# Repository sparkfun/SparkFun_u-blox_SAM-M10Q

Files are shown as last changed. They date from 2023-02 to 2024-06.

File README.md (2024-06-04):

SparkFun GPS Breakout, Chip Antenna - SAM-M10Q (Qwiic)
========================================

SparkFun GPS Breakout, Chip Antenna - SAM-M10Q (Qwiic) (https://www.sparkfun.com/products/21834)

[*SparkFun GPS Breakout, Chip Antenna - SAM-M10Q (Qwiic) (GPS-21834)*](https://www.sparkfun.com/products/21834)

The SparkFun SAM-M10Q GPS Breakout features the the SAM-M10Q chip-antenna module from u-blox<sup>&copy;</sup>. The SAM-M10Q can receive up to four GNSS constellations at once which improves time-to-fix and positional accuracy even in areas with limited view of the sky. The module includes a built-in chip antenna and is compatible with the L1 band on all five GNSS constellations (GPS L1 C/A, QZSS L1 C/A L1S, GLONASS L1OF, BeiDou B1C, and Galileo E1B/C). It has a horizontal position accuracy of 1.5 m, max update rate of 18 Hz when transmitting with just one GNSS constellation (max of 5Hz with 4 GNSS) and a cold start time to fix of 23 seconds. The board includes a rechargeable 3V/1mAh battery to provide backup power for up to four hours to maintain a hot start of just 1 second.

Repository Contents
-------------------

* **/Documentation** - Data sheets, additional product information
* **/Hardware** - Eagle design files (.brd, .sch)
* **/docs** - Hookup Guide files for the GPS Breakout, Chip Antenna - SAM-M10Q (Qwiic)
* **/Production** - Production panel files (.brd)

Documentation
--------------
* **[Library](https://github.com/sparkfun/SparkFun_u-blox_GNSS_v3)** - Arduino library for the SparkFun u-blox boards v3.
* **[Hookup Guide](https://docs.sparkfun.com/SparkFun_u-blox_SAM-M10Q)** - Basic hookup guide for the GPS Breakout, Chip Antenna - SAM-M10Q (Qwiic).

Product Versions
----------------

* [GPS-21834](https://www.sparkfun.com/products/21834) - Initial release of GPS Breakout, Chip Antenna - SAM-M10Q (Qwiic)

License Information
-------------------

This product is _**open source**_! 

Please review the LICENSE.md file for license information. 

If you have any questions or concerns on licensing, please contact technical support on our [SparkFun forums](https://forum.sparkfun.com/viewforum.php?f=152).

Distributed as-is; no warranty is given.

- Your friends at SparkFun.

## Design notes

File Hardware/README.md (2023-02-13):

SparkFun <PRODUCT NAME> Design Files
=====================================

The .sch and .brd files hare are Eagle CAD schematic and PCB design files from SparkFun Electronics.
A freeware version of Autodesk Eagle can be found [here](https://www.autodesk.com/products/eagle/free-download).

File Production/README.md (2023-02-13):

SparkFun <PRODUCT NAME> Production Files
=========================================

These are the production files SparkFun uses for printing PCBs.

License Information
-------------------
This product is open source! 

The hardware is released under [Creative Commons ShareAlike 4.0 International](https://creativecommons.org/licenses/by-sa/4.0/).

Please use, reuse, and modify these files as you see fit. Please maintain attribution to SparkFun Electronics and release anything derivative under the same license.

Distributed as-is; no warranty is given.

- Your friends at SparkFun.

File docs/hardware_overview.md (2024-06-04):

Let&apos;s take a closer look at the SAM-M10Q and other hardware on this GPS breakout.

## SAM-M10Q

The SAM-M10Q GNSS module from u-blox is from the M10 series of modules and features a chip antenna. The chip antenna removes the need for an external antenna and we designed this board to mount the module on a large ground plane to help maximize the reception quality. 

<center>
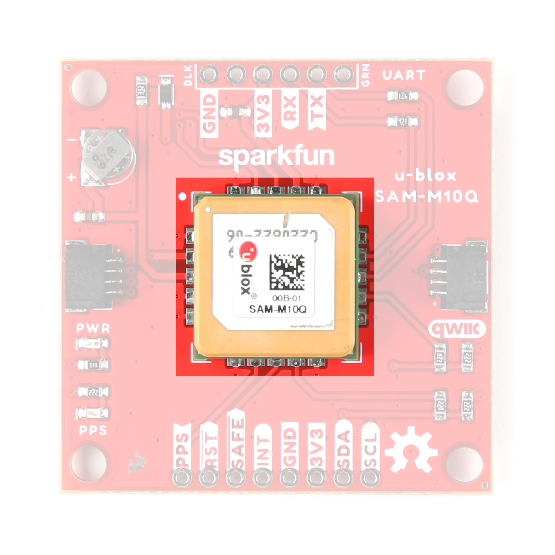
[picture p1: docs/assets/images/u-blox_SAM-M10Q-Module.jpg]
SAM-M10Q Module

</center>

The module can receive up to four GNSS constellations at a time allowing for excellent signal quality and reliability even in areas with limited view of the sky. More GNSS locks reduce the update rate of the SAM-M10Q so users should take into consideration which is more important for their application. The SAM-M10Q has a max altitude of 80,000m and max velocity of 500m/s with an acceleration limit of &le; 4g. The module also has a time pulse signal with a RMS accuracy of 30ns. This signal defaults to 1 pulse per second but is configurable between 0.25Hz to 10MHz. For a complete overview of the SAM-M10Q refer to the [datasheet](./assets/component_documentation/SAM-M10Q_DataSheet_UBX-22013293.pdf) and [integration manual](./assets/component_documentation/SAM-M10Q_IntegrationManual_UBX-22020019.pdf). The tables below outline some of the SAM-M10Q&apos;s capabilities in single-GNSS and multi-GNSS modes:

<table>
    <th colspan="7"><b>Single GNSS Constellation Mode</b></th>
    <tr align="center">
        <td align="left">Parameter</td>
        <td>Condition</td>
        <td>Units</td>    
        <td>GPS</td>    
        <td>GLONASS</td>        
        <td>Galileo</td> 
        <td>BeiDou</td>
    </tr>   
    <tr align="center">
        <td align="left">Horizontal Position Accuracy</td>
        <td>-</td>
        <td>m</td>
        <td>1.5</td>
        <td>4</td>
        <td>3</td>
        <td>2</td>
    </tr>
    <tr align="center">
        <td align="left">Max Navigation Update Rate</td>
        <td>-</td>
        <td>Hz</td> 
        <td>18</td>
        <td>18</td>
        <td>18</td>
        <td>18</td>       
    </tr> 
    <tr align="center">
        <td rowspan="2" align="left">Time-To-First-Fix</td>
        <td>Cold Start</td>
        <td rowspan="2">s</td>
        <td>29</td>
        <td>27</td>
        <td>41</td>
        <td>56</td>
    </tr>
    <tr align="center"> 
        <td>Hot Start</td>
        <td>1</td> 
       	<td>1</td>
        <td>1</td> 
        <td>1</td>
    </tr>
    <tr align="center">
        <td align="left" rowspan="4">Sensitivity</td>
        <td>Cold Start</td>
        <td rowspan="4">dBm</td>
        <td>-146</td>
        <td>-145</td> 
        <td>-139</td> 
        <td>-134</td>
    </tr>
    <tr align="center"> 
        <td>Hot Start</td> 
        <td>-157</td> 
        <td>-157</td>
        <td>-153</td> 
        <td>-155</td>
    </tr>   
    <tr align="center">
        <td>Tracking and Navigation</td>
        <td>-165</td>
        <td>-164</td>
        <td>-159</td> 
        <td>-161</td> 
    </tr>
    <tr align="center">
        <td>Reacquisition</td> 
        <td>-158</td> 
        <td>-156</td> 
        <td>-152</td> 
        <td>-154</td> 
    </tr>
</table>
<table>
    <th colspan="7">Multi-GNSS Constellation Modes</th>
    <tr align="center">
        <td align="left">Parameter</td>
        <td>Condition</td>
        <td>Units</td>
        <td>GPS+GAL+BDS+GLO</td>
        <td>GPS+GAL+GLO</td>
        <td>GPS+GAL+BDS</td>
        <td>GPS+GAL</td>
    </tr>
    <tr align="center">
        <td align="left">Max Navigation Update Rate</td>
        <td>-</td>
        <td>Hz</td>
        <td>5</td>
        <td>7</td>
        <td>8</td>
        <td>10</td>
    </tr>
    <tr align="center">
        <td align="left">Horizontal Position Accuracy</td>
        <td>-</td>
        <td>m</td>
        <td>1.5</td>
        <td>1.5</td>
        <td>1.5</td>
        <td>1.5</td>
    </tr>
    <tr align="center">
        <td align="left" rowspan="2">Time-To-First-Fix</td>
        <td>Cold Start</td>
        <td rowspan="2">s</td>
        <td>23</td>
        <td>23</td>
        <td>28</td>
        <td>28</td>
    </tr>
    <tr align="center">
        <td>Hot Start</td>
        <td>1</td>
        <td>1</td>
        <td>1</td>
        <td>1</td>
    </tr>
    <tr align="center">
        <td align="left" rowspan="4">Sensitivity</td>
        <td>Tracking and Navigation</td>
        <td rowspan="4">dBm</td>
        <td>-165</td>
        <td>-165</td>
        <td>-165</td>
        <td>-165</td>
    </tr>
    <tr align="center">
        <td>Reacquisition</td>
        <td>-158</td>
        <td>-158</td>
        <td>-158</td>
        <td>-158</td>
    </tr>
    <tr align="center">
        <td>Cold Start</td>
        <td>-146</td>
        <td>-146</td>
        <td>-146</td>
        <td>-146</td>
    </tr>
    <tr align="center">
        <td>Hot Start</td>
        <td>-157</td>
        <td>-157</td>
        <td>-157</td>
        <td>-157</td>
    </tr>
</table>

## Backup Battery

This breakout includes a small 3V/1mAh lithium battery to power relevant systems inside the SAM-M10Q that allow for a quick acquisition of satellites. On first start up, time to first fix is about ~23 seconds, but after it has a lock the battery allows for a hot start and can drop the time to fix down to one second. A hot start and lasts for four hours after the board is powered down and the board charges it slowly when powered.

<center>
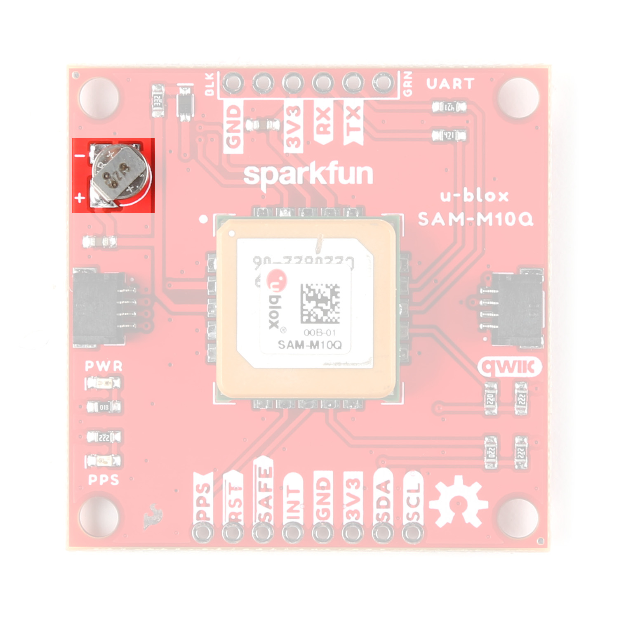
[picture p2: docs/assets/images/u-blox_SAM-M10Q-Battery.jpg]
Backup Battery

</center>

## Qwiic & Through Hole Connections

As the name suggests, this breakout includes a pair of Qwiic connectors to integrate the SAM-M10Q into an existing Qwiic system. The board also includes a pair of 0.1"-spaced plated through hole (PTH) headers for the SAM-M10Q's UART interface as well as several other function pins.

<center>
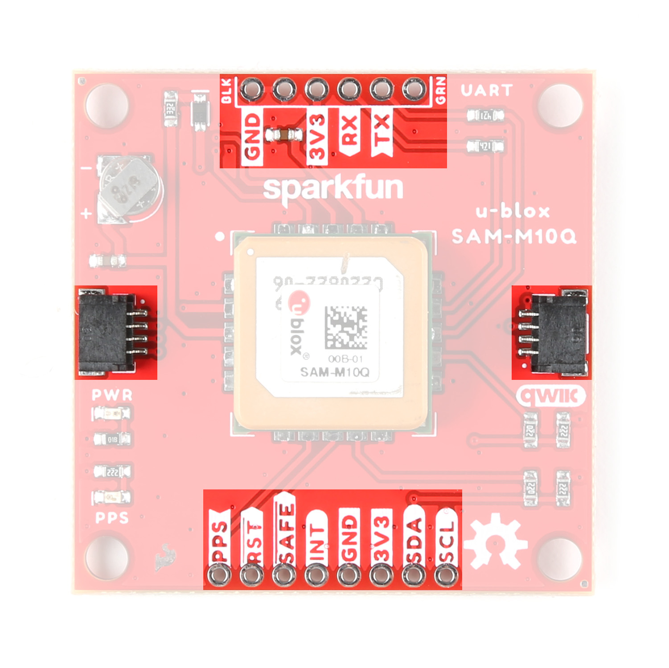
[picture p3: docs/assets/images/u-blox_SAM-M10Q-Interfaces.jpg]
Communication Interfaces

</center>

### Qwiic Connectors

The two Qwiic connectors route the I<sup>2</sup>C lines (SDA/SCL) as well as 3.3V and Ground allowing for power and I<sup>2</sup>C communication with no soldering required. These connectors offer the best and easiest way to get started using this board with the SparkFun u-blox GNSS Arduino Library as many of the examples included in it assume an I<sup>2</sup>C connection between the SAM-M10Q and microcontroller.

### Plated Through Hole Headers

The breakout also includes two sets of 0.1"-spaced plated through hole (PTH) headers. One routes the SAM-M10Q&apos;s UART interface to a header matching the pinout of our [Serial Basic](https://www.sparkfun.com/products/15096) and other USB-to-UART boards. The other routes the I<sup>2</sup>C interface, interrupt (INT), safeboot (SAFE), reset (RST), and time pulse (PPS) pins.

The UART header mates with a <b>3.3V</b> Serial Basic or other USB-to-UART converter. Make sure a connected converter runs at <b>3.3V</b> and not <b>5V</b>.

The PPS outputs pulse trains synchronized with the GPS or UTC time grid. The signal defaults to once per second but is configurable over a wide range. Read the u-blox Receiver Protocol Specification in the Resources and Going Further section for more information. The Reset (RST) pin resets the chip. The next pin, SAFE is used to start up the IC in safe boot mode. The final pin INT can be used to wake the chip from power save mode.

## LEDs

The board has two LEDs labeled <b>PWR</b> and <b>PPS</b>. The Power (PWR) LED indicates when the board is powered. The Pulse Per Second (PPS) LED connects to the module&apos;s timepulse pin. This signal generates a pulse that is synchronized with a GPS or UTC time grid. By default, it pulses once every second but can be adjuted to different time values. 

<center>
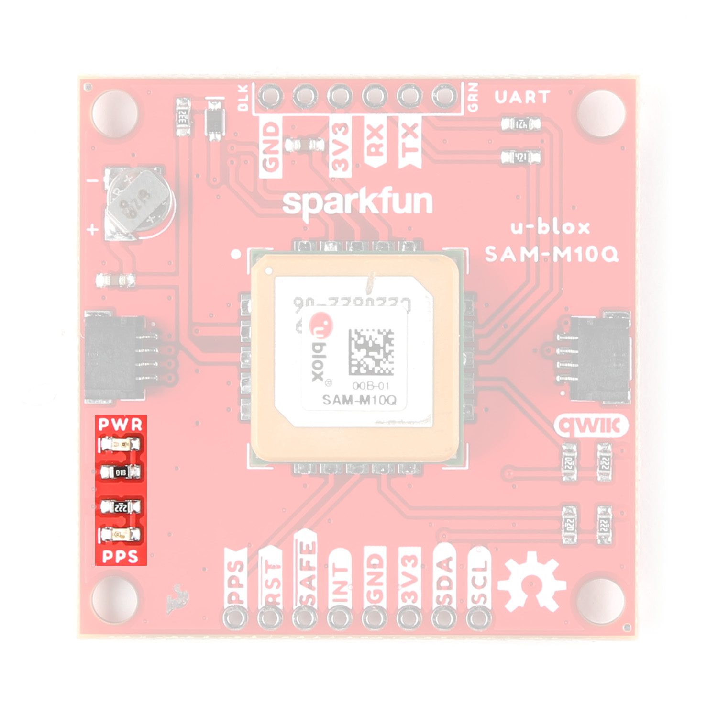
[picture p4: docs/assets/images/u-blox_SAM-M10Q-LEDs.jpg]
LEDs

</center>

## Solder Jumpers

There are three solder jumpers on the board labeled: <b>I2CPUR</b>, <b>PWRLED</b> and <b>PPSLED</b>. 

<center>
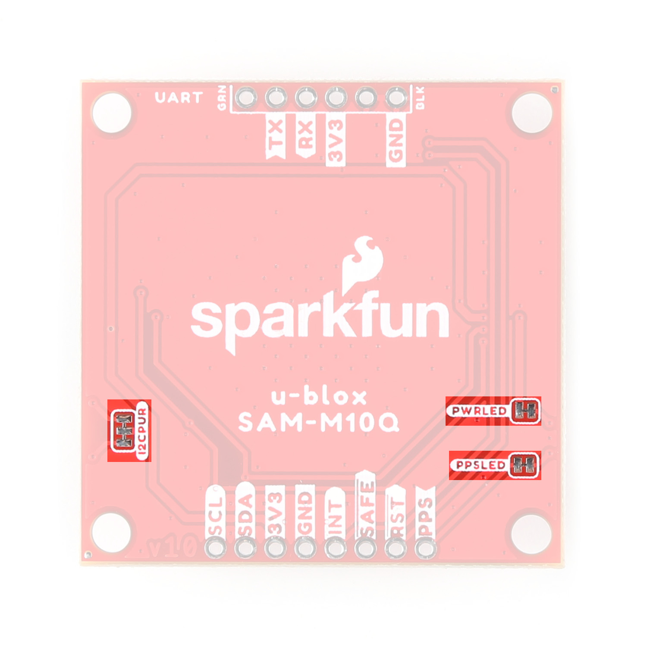
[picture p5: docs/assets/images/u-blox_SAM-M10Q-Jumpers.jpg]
Solder Jumpers

</center>

The I2CPUR is a three-way jumper connecting the SDA/SCL lines to 3.3V through a pair of <b>2.2k&ohm;</b> resistors. Open the jumper completely by severing the traces between all three pads to disable the pullup resistors on the I<sup>2</sup>C bus. The other two jumpers complete the power circuits for their respective LEDs (Power and Pulse Per Second). Open the solder jumpers to disable these LEDs to reduce total power consumption of the board.

## Board Dimensions 

This GPS breakout is slightly bigger than a typical Qwiic board due to the expanded ground plane around the SAM-M10Q module and measures 1.6" x 1.6" (40.64mm x 40.64mm). The board includes four mounting holes that fit a [4-40 screw](https://www.sparkfun.com/products/10453).

<center>
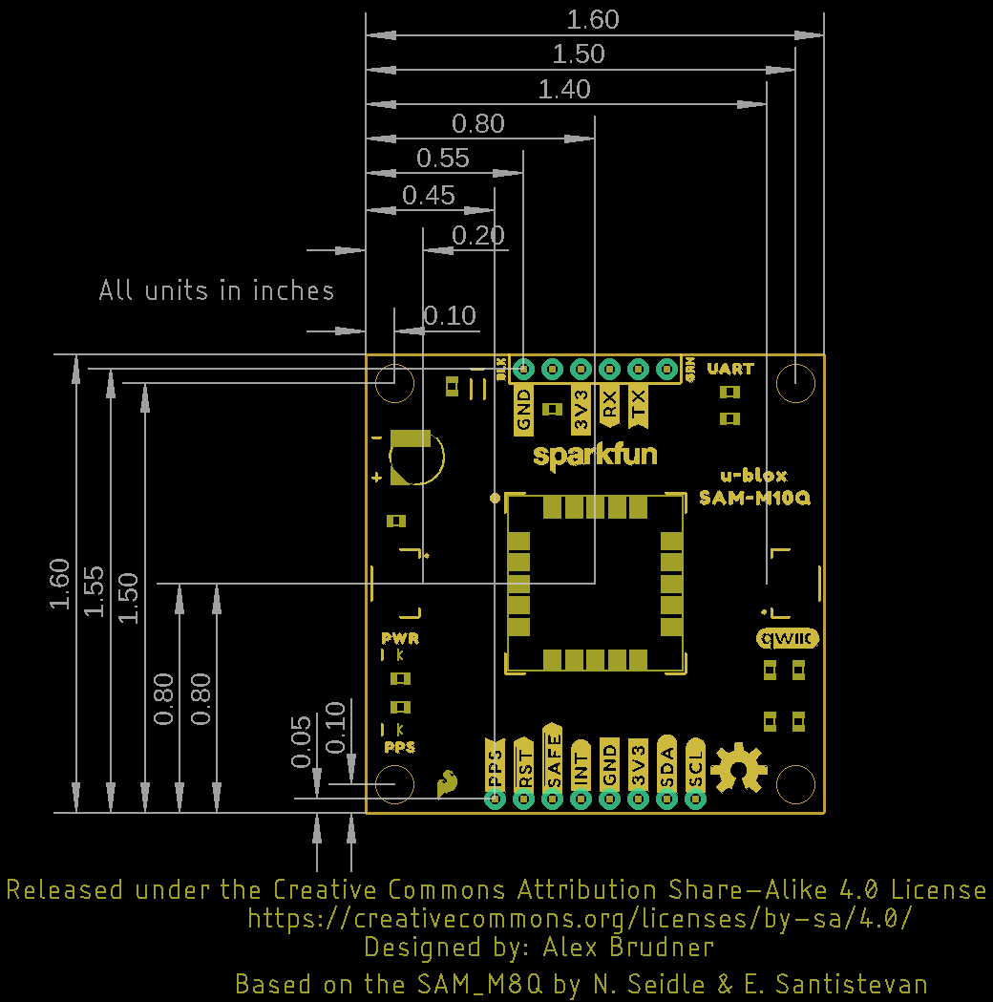
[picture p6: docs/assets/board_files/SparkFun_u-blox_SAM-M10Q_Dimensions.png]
Board Dimensions

</center>

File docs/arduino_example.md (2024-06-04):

Now let's take a closer look at the basic GNSS position example included in the SparkFun u-blox GNSS Arduino Library.

## Example 1 - Position, Velocity, Time

The first example in the library demonstrates initializing the SAM-M10Q (or any other supported u-blox module) and then receiving position, velocity, and time data from the module. Open the example by navigating to <b>'File'</b> < <b>'Examples'</b> < <b>'SparkFun u-blox GNSS v3'</b> < <b>'Example1_PositionVelocityTime'</b>. Select your <b>Board</b> and <b>Port</b> and click <b>'Upload</b>. Once the code finishes uploading, open the [serial monitor](https://learn.sparkfun.com/tutorials/terminal-basics) with the baud set to <b>115200</b>.

For the best results, make sure the SAM-M10Q has a clear view of the open sky. The first time running this example will take ~23 seconds for the module to get a lock onto any satellites. After this initial cold start, the battery on the board will provide power to the hot start circuitry in the module to assist with warm/hot starts during power cycles to drop the time-to-fix down to just one second. This hot start lasts up to four hours between power cycles.

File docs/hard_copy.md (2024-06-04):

---
icon: fontawesome/solid/print
# material/book-open-variant
---

# Hard Copies

Need to download or print our hookup guide?

* [Print :fontawesome-solid-print:](../single_page) *from Single-Page View*
<!-- * [Download :fontawesome-regular-file-pdf:](../assets/board_files/hookup_guide.pdf) *(Beta - Mostly works, but some attributes may be broken.)* -->

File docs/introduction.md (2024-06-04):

<div class="grid cards desc" markdown>

<!-- **SparkFun GPS Breakout - Chip Antenna, SAM-M10Q (Qwiic)** (GPS-21834)> -->
-   **SKU:** GPS-21834

    ---

    <figure markdown>
    SparkFun GPS Breakout, Chip Antenna - SAM-M10Q (Qwiic) (https://www.sparkfun.com/products/21834)
    </figure>

-   The [SparkFun SAM-M10Q GPS Breakout](https://www.sparkfun.com/products/21834) features the the SAM-M10Q chip-antenna module from u-blox<sup>&copy;</sup>. The M10Q line is the successor to u-blox&apos;s M8Q found on the [SparkFun GPS Breakout - Chip Antenna, SAM-M8Q (Qwiic)](https://www.sparkfun.com/products/15210) and is a drop-in replacement with updated features to reduce power consumption while also improving performance. The SAM-M10Q can receive up to four GNSS constellations at once which improves time-to-fix and positional accuracy even in areas with limited view of the sky.<br>
    Utilizing our handy Qwiic system, no soldering is required to connect it to the rest of your system. However, the board still breaks out 0.1"-spaced pins for users who prefer a soldered connection or prototyping on a breadboard.

    <center>
    [Purchase from SparkFun :fontawesome-solid-cart-plus:](https://www.sparkfun.com/products/21834){ .md-button .md-button--primary }
    </center>

</div>

This guide covers the hardware present on this GPS breakout, how to assemble it into a Qwiic circuit and how to use it with the SparkFun u-blox Arduino Library v3.

## Required Materials

To follow along with this guide you will need a microcontroller to communicate with the SAM-M10Q Breakout. Below are a few options that come Qwiic-enabled out of the box:

<div class="grid cards" markdown>

-   <a href="https://www.sparkfun.com/products/20168">

    <figure markdown>
    SparkFun Thing Plus - ESP32 WROOM (USB-C)
    </figure>
    </a>

    ---

    <a href="https://www.sparkfun.com/products/20168">
    **SparkFun Thing Plus - ESP32 WROOM (USB-C)**<br>
    DEV-20168
    </a>

-   <a href="https://www.sparkfun.com/products/18158">
    
    <figure markdown>
    SparkFun RedBoard Plus
    </figure>
    </a>

    ---

    <a href="https://www.sparkfun.com/products/18158">
    **SparkFun RedBoard Plus**<br>
    DEV-18158
    </a>

-   <a href="https://www.sparkfun.com/products/15574">
    
    <figure markdown>
    SparkFun Thing Plus - Artemis
    </figure>
    </a>

    ---

    <a href="https://www.sparkfun.com/products/15574">
    **SparkFun Thing Plus - Artemis**<br>
    DEV-18158
    </a>

-   <a href="https://www.sparkfun.com/products/15444">

    <figure markdown>
    SparkFun RedBoard Artemis
    </figure>
    </a>

    ---

    <a href="https://www.sparkfun.com/products/15444">**SparkFun RedBoard Artemis**<br>
    DEV-15444
    </a>
</div>

If your chosen microcontroller is not already Qwiic-enabled, you can add that functionality with one or more of the following items:

<div class="grid cards" markdown>

-   <a href="https://www.sparkfun.com/products/15081">

    <figure markdown>
    SparkFun Qwiic Cable Kit)
    </figure>
    </a>

    ---

    <a href="https://www.sparkfun.com/products/15081">
    **SparkFun Qwiic Cable Kit**<br>
    KIT-15081
    </a>

-   <a href="https://www.sparkfun.com/products/14495">
    
    <figure markdown>
    SparkFun Qwiic Adapter
    </figure>
    </a>

    ---

    <a href="https://www.sparkfun.com/products/14495">
    **SparkFun Qwiic Adapter**<br>
    DEV-14495
    </a>

-   <a href="https://www.sparkfun.com/products/14352">
    
    <figure markdown>
    SparkFun Qwiic Shield for Arduino
    </figure>
    </a>

    ---

    <a href="https://www.sparkfun.com/products/14352">
    **SparkFun Qwiic Shield for Arduino**<br>
    DEV-14352
    </a>

-   <a href="https://www.sparkfun.com/products/16790">

    <figure markdown>
    SparkFun Qwiic Shield for Thing Plus
    </figure>
    </a>

    ---

    <a href="https://www.sparkfun.com/products/16790">
    **SparkFun Qwiic Shield for Thing Plus**<br>
    DEV-16790
    </a>
</div>

You will also need at least one Qwiic cable to connect your GPS breakout to your microcontroller:

<div class="grid cards" markdown>

-   <a href="https://www.sparkfun.com/products/17259">

    <figure markdown>
    Flexible Qwiic Cable - 100mm)
    </figure>
    </a>

    ---

    <a href="https://www.sparkfun.com/products/17259">
    **Flexible Qwiic Cable - 100mm**<br>
    PRT-17259
    </a>

-   <a href="https://www.sparkfun.com/products/17260">
    
    <figure markdown>
    Qwiic Cable - 50mm
    </figure>
    </a>

    ---

    <a href="https://www.sparkfun.com/products/17260">
    **Flexible Qwiic Cable - 50mm**<br>
    PRT-17260
    </a>

-   <a href="https://www.sparkfun.com/products/17257">
    
    <figure markdown>
    Flexible Qwiic Cable - 500mm
    </figure>
    </a>

    ---

    <a href="https://www.sparkfun.com/products/17257">
    **Flexible Qwiic Cable - 500mm**<br>
    PRT-17257
    </a>

-   <a href="https://www.sparkfun.com/products/17261">

    <figure markdown>
    Flexible Qwiic Cable - Female Jumper (4-pin)
    </figure>
    </a>

    ---

    <a href="https://www.sparkfun.com/products/17261">**Flexible Qwiic Cable - Female Jumper (4-pin)**<br>
    CAB-17261
    </a>
</div>

## Optional Materials

If you prefer a soldered connection or want to modify the solder jumpers on this board, you may need some of the products listed below:

<div class="grid cards" markdown align="center">

-   <a href="https://www.sparkfun.com/products/116">

    <figure markdown>
    Break Away Headers - Straight)
    </figure>
    </a>

    ---

    <a href="https://www.sparkfun.com/products/116">
    **Break Away Headers - Straight**<br>
    PRT-00116
    </a>

-   <a href="https://www.sparkfun.com/products/14681">
    
    <figure markdown>
    SparkFun Beginner Tool Kit
    </figure>
    </a>

    ---

    <a href="https://www.sparkfun.com/products/14681">
    **SparkFun Beginner Tool Kit**<br>
    TOL-14681
    </a>

-   <a href="https://www.sparkfun.com/products/9200">
    
    <figure markdown>
    Hobby Knife
    </figure>
    </a>

    ---

    <a href="https://www.sparkfun.com/products/9200">
    **Hobby Knife**<br>
    TOL-09200
    </a>

-   <a href="https://www.sparkfun.com/products/14579">

    <figure markdown>
    Chip Quik No-Clean Flux Pen - 10mL
    </figure>
    </a>

    ---

    <a href="https://www.sparkfun.com/products/14579">**Chip Quik No-Clean Flux Pen - 10mL**<br>
    CAB-14579
    </a>
</div>

## Suggested Reading

We designed this board for integration into SparkFun's Qwiic connect system.  Click on the banner below to learn more about the [SparkFun Qwiic Connect System](https://www.sparkfun.com/qwiic).

<div style="text-align: center">
<table>
  <tr>
   <td>
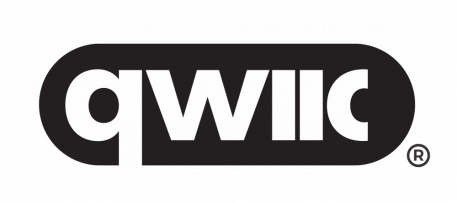
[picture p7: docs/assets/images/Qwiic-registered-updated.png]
Qwiic Connect System Click to learn more about the Qwiic Connect System!
   <div style="text-align: center"></div>
   </td>
  </tr>
  <tr>
    <td><div style="text-align: center"><i><a href="https://www.sparkfun.com/qwiic">Qwiic Connect System</a></i></div></td>
  </tr>
</table>
</div>

Before getting started with this Hookup Guide, you may want to read through the tutorials below if you are not familiar with the concepts covered in them or want a refresher. If you are using either of the Qwiic Shields linked above, we recommend reading through their respective Hookup Guides before continuing with this tutorial:

<div class="grid cards" markdown align="center">

-   <a href="https://learn.sparkfun.com/tutorials/9">

    <figure markdown>
    GPS Basics
    </figure>
    </a>

    ---

    <a href="https://learn.sparkfun.com/tutorials/9">**GPS Basics**
    </a>

-   <a href="https://learn.sparkfun.com/tutorials/8">

    <figure markdown>
    Serial Communication
    </figure>
    </a>

    ---

    <a href="https://learn.sparkfun.com/tutorials/8">**Serial Communication**
    </a>

-   <a href="https://learn.sparkfun.com/tutorials/82">

    <figure markdown>
    I2C
    </figure>
    </a>

    ---

    <a href="https://learn.sparkfun.com/tutorials/82">**I2C**
    </a>

-   <a href="https://learn.sparkfun.com/tutorials/16">

    <figure markdown>
    Serial Peripheral Interface (SPI)
    </figure>
    </a>

    ---

    <a href="https://learn.sparkfun.com/tutorials/16">**Serial Peripheral Interface (SPI)**
    </a>

-   <a href="https://learn.sparkfun.com/tutorials/62">

    <figure markdown>
    Logic Levels
    </figure>
    </a>

    ---

    <a href="https://learn.sparkfun.com/tutorials/62">**Logic Levels**
    </a>

-   <a href="https://learn.sparkfun.com/tutorials/664">

    <figure markdown>
    How to Work with Jumper Pads and PCB Traces
    </figure>
    </a>

    ---

    <a href="https://learn.sparkfun.com/tutorials/664">**How to Work with Jumper Pads and PCB Traces**
    </a>

-   <a href="https://learn.sparkfun.com/tutorials/815">

    <figure markdown>
    Getting Started with u-center
    </figure>
    </a>

    ---

    <a href="https://learn.sparkfun.com/tutorials/815">**Getting Started with u-center**
    </a>

-   <a href="https://learn.sparkfun.com/tutorials/684">

    <figure markdown>
    Qwiic Shield for Arduino & Photon Hookup Guide
    </figure>
    </a>

    ---

    <a href="https://learn.sparkfun.com/tutorials/684">**Qwiic Shield for Arduino & Photon Hookup Guide**
    </a>

-   <a href="https://learn.sparkfun.com/tutorials/1107">

    <figure markdown>
    Qwiic Shield for Thing Plus Hookup Guide
    </figure>
    </a>

    ---

    <a href="https://learn.sparkfun.com/tutorials/1107">**Qwiic Shield for Thing Plus Hookup Guide**
    </a>
</div>

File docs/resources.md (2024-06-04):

That's all for this tutorial. For more information about the SparkFun GPS Breakout - Chip Antenna, SAM-M10Q (Qwiic), take a look at the following resources:

* [Schematic](./assets/board_files/SparkFun_u-blox_SAM-M10Q.pdf)
* [Eagle Files](./assets/board_files/SparkFun_u-blox_SAM-M10Q.zip)
* [Board Dimensions](./assets/board_files/SparkFun_u-blox_SAM-M10Q_Dimensions.png)
* [Datasheet](./assets/component_documentation/SAM-M10Q_DataSheet_UBX-22013293.pdf)
* [Integration Manual](./assets/component_documentation/SAM-M10Q_IntegrationManual_UBX-22020019.pdf)
* [Product Summary](./assets/component_documentation/SAM-M10Q_ProductSummary_UBX-22004868.pdf)
* [M10 SPG 5.10 Firmware Interface Description](./assets/component_documentation/u-blox-M10-SPG-5.10_InterfaceDescription_UBX-21035062.pdf)
* [u-center Software](https://www.u-blox.com/en/product/u-center)
* [SparkFun u-blox GNSS Arduino Library - v3](https://github.com/sparkfun/SparkFun_u-blox_GNSS_v3)
* [GitHub Hardware Repository](https://github.com/sparkfun/SparkFun_u-blox_SAM-M10Q)

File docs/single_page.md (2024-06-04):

---
hide:
  - navigation
  - toc
icon: fontawesome/solid/scroll
---

# Introduction
--8<-- "./docs/introduction.md"

# Hardware Overview
--8<-- "./docs/hardware_overview.md"

# Hardware Assembly
--8<-- "./docs/hardware_assembly.md"

# Software Overview
--8<-- "./docs/arduino_setup.md"

# Arduino Examples
--8<-- "./docs/arduino_example.md"

# Troubleshooting
--8<-- "./docs/troubleshooting.md"

# Resources:
--8<-- "./docs/resources.md"

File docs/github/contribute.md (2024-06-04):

# Help Improve the Experience!
Spot an improvement opportunity? Feel free to contribute to our open-source design and documentation. 

## Enhance our Documentation
All of this documentation can be modified by you! Please help us make it better.

* These pages are contained in the [`docs` folder](https://github.com/sparkfun/SparkFun_u-blox_SAM-M10Q/tree/main/docs) of the [SparkFun GPS Breakout - Chip Antenna, SAM-M10Q (Qwiic)](https://github.com/sparkfun/SparkFun_u-blox_SAM-M10Q) repository.

### Submit a Correction
1. Fork this repo
2. Add your corrections or improvements to the markdown file
3. File a pull request with your changes, and enjoy making the ~~words~~ ~~worlds~~ world a better place.
	* Once received, the documentation specialist will automatically be notified.
	* We will review your suggested improvements to make sure they are correct and fit within our documentation standards.

## Upgrade our Hardware Design
All of our designs are open-source! Please help us make it better.

* Our board design files are contained in the [`Hardware` folder](https://github.com/sparkfun/SparkFun_u-blox_SAM-M10Q/tree/main/Hardware) of the [SparkFun GPS Breakout - Chip Antenna, SAM-M10Q (Qwiic)](https://github.com/sparkfun/SparkFun_u-blox_SAM-M10Q) repository.

### Submit a Design Improvement
1. Fork this repo
2. Add your design modifications
3. File a pull request with your changes, and enjoy making the world a better place.
	* Once received, the engineer in charge of the original design will automatically be notified.
	* We will review your suggested upgrades, if they are within our board design standards and meet our product design requirements, we will flag these changes for our next board revision.
	
	!!! note
		Please note, that even if your suggestion is accepted, these changes may not be immediate. We may have to cycle through our current product inventory first.

## Contributors
Let's provide some recognition to those who have contributed to this project!

GitHub Contributors Image
<br>


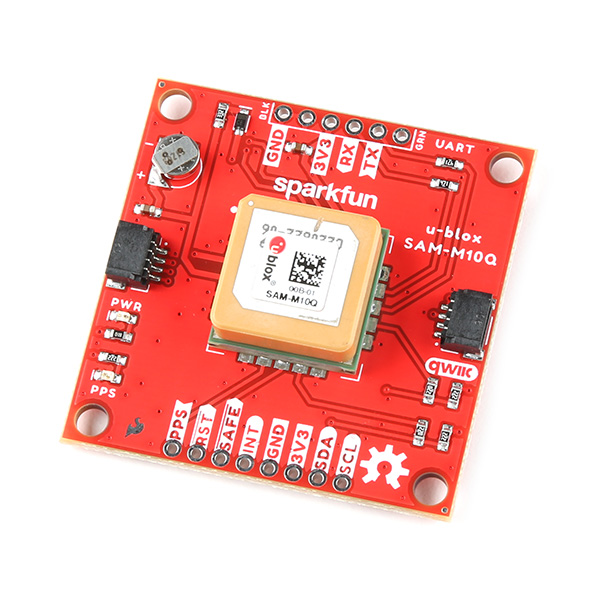
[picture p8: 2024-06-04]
site/assets/images/u-blox_SAM-M10Q-Thumb.jpg

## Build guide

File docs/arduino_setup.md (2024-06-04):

The SAM-M10Q works with the latest version of the SparkFun u-blox GNSS Arduino Library, v3. Install the library using Arduino's Library Manager Tool by searching for <b>'SparkFun u-blox GNSS v3'</b>. If you prefer to manually install the library you can download the [GitHub repository](https://github.com/sparkfun/SparkFun_u-blox_GNSS_v3) or download a ZIP of it here:

<center>
[SparkFun u-blox GNSS v3 (ZIP)](https://github.com/sparkfun/SparkFun_u-blox_GNSS_v3/archive/refs/heads/main.zip){ .md-button .md-button--primary }
</center>

The third version of this library complies with u-blox's updated UBX protocol that depreciates the UBX-CFG commands. These still work but are depreciated and u-blox now recommends using the updated VALSET, VALGET, and VALDEL commands included in v3 of the library. With the library installed, let's move on to taking a look at a couple of examples from the library.

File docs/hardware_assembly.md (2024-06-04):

Now that we're familiar with the hardware on this breakout, let's assemble it into a Qwiic circuit with the [SparkFun RedBoard Artemis]().

## Qwiic Assembly

With the Qwiic system, simply connect the GNSS Breakout to your chosen Qwiic-enabled microcontroller (in this case the RedBoard Artemis) using a Qwiic cable like the image below:

<center>
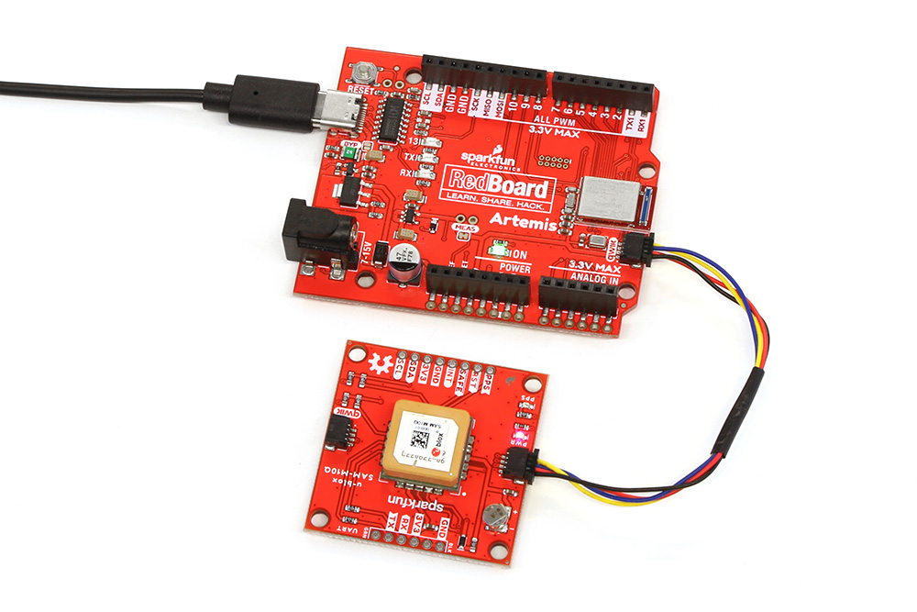
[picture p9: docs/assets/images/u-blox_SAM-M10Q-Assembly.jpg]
Qwiic Assembly

</center>

Since the SAM-M10Q has an on-chip antenna, no external antenna is required so just plug your microcontroller into your computer and start using the board with the SparkFun u-blox Arduino Library.

## Soldered Assembly

If you prefer to configure and use the SAM-M10Q's with u-center either through UART or I<sup>2</sup>C or if you want a traditional soldered connection should solder to the board's PTH headers. If you've never done through-hole soldering before or would like a refresher or tips, check out our [How to Solder: Through-Hole Soldering](https://learn.sparkfun.com/tutorials/5) tutorial:

<div class="grid cards" markdown>
-   <a href="https://learn.sparkfun.com/tutorials/5">
    <figure markdown>
    How to Solder: Through-Hole Soldering
    </figure>
    </a>
</div>

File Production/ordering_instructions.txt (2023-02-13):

panel size, 178x137mm
PCB thickness, 1.6mm
number of layers, 2
soldermask color, Red
silkscreen color, White
oz copper, 1oz
finish, HASL lead free
stencils, top
pcs per panel, 12
min trace width, 0.3810mm / 0.0150in
min drill size, 0.3810mm / 0.0150in

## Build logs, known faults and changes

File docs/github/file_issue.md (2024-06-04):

# Did we make a mistake?

Spot something wrong? Please let us know. 

!!! attention
	This is not where customers should seek assistance on a product. If you require technical assistance or have questions about a product that is not working as expected, please head over to the [SparkFun Technical Assistance](https://www.sparkfun.com/technical_assistance) page for some initial troubleshooting.
    <center>
    [SparkFun Technical Assistance Page](https://www.sparkfun.com/technical_assistance){ .md-button .md-button--primary }
    </center>
    
    If you can't find what you need there, the [SparkFun Forums](https://forum.sparkfun.com/index.php) is a great place to search product forums and ask questions.
    
    !!! info "Account Registration Required"
        If this is your first visit to our forum, you'll need to create a [Forum Account](https://forum.sparkfun.com/ucp.php?mode=register) to search product forums and post questions.

## Discrepancies in the Documentation

All of this documentation can be modified by you! Please help us make it better.

* The documentation files for these pages are contained in the [`docs` folder](https://github.com/sparkfun/SparkFun_u-blox_SAM-M10Q/tree/main/docs) of the [SparkFun GPS Breakout - Chip Antenna, SAM-M10Q (Qwiic)](https://github.com/sparkfun/SparkFun_u-blox_SAM-M10Q) repository.

### Spot something wrong?
If a section of the documentation is incorrect, please [open an issue](https://github.com/sparkfun/SparkFun_u-blox_SAM-M10Q/issues) and let us know.

### Do you have a suggested correction?
1. With a GitHub account, fork this repo
2. Add your correction(s) or improvement(s) to the markdown file(s)
3. File a pull request with your changes, and enjoy making the ~~words~~ ~~worlds~~ world a better place.
	* Once received, the documentation specialist will automatically be notified.
	* We will review your suggested improvement(s) to make sure they are correct and fit within our documentation standards.

## Problems in the Hardware Design

All of our designs are open-source! Please help us make it better.

* Our board design files are contained in the [`Hardware` folder](https://github.com/sparkfun/SparkFun_u-blox_SAM-M10Q/tree/main/Hardware) of the [SparkFun GPS Breakout - Chip Antenna, SAM-M10Q (Qwiic)](https://github.com/sparkfun/SparkFun_u-blox_SAM-M10Q) repository.

### Does something not make sense?
If part of the design is confusing, please [open an issue](https://github.com/sparkfun/SparkFun_u-blox_SAM-M10Q/issues) and let us know.

### Did we forget to include an important function of the board?
* Please keep in mind that we may intentionally exclude certain functions of the board to meet our product design requirements. *(For example, our Qwiic Micro boards are intended to fit on a small board layout and only use I<sup>2</sup>C communication; therefore, we may not have the SPI and interrupt pins available for users.)*
* If part of the board's functionality is missing, please [open an issue](https://github.com/sparkfun/SparkFun_u-blox_SAM-M10Q/issues) and file a feature request.

### Do you wish to contribute directly to improving the board design?
1. With a GitHub account, Fork this repo
2. Add your design improvement(s)
3. File a pull request with your changes, and enjoy making the ~~words~~ ~~worlds~~ world a better place.
	* Once received, the engineer in charge of the original design will automatically be notified.
	* We will review your suggested improvement(s), if they are within our board design standards and meet our product design requirements, we will flag these changes for our next board revision. *(Please note, that even if your suggestion is accepted, these changes may not be immediate. We may have to cycle through our current product inventory first.)*

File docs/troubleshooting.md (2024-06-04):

!!! warning "Need Help?"
    If you need technical assistance or more information on a product that is not working as you expected, we recommend heading on over to the [SparkFun Technical Assistance](https://www.sparkfun.com/technical_assistanc) page for some initial troubleshooting.

    <center>
    [SparkFun Technical Assistance Page](https://www.sparkfun.com/technical_assistance){ .md-button .md-button--primary }
    </center>
    
    If you can't find what you need there, the [SparkFun Forums](https://forum.sparkfun.com/index.php) is a great place to search product forums and ask questions.
    
    !!! info "Account Registration Required"
        If this is your first visit to our forum, you'll need to create a [Forum Account](https://forum.sparkfun.com/ucp.php?mode=register) to post questions.

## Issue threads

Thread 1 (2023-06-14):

config-security-lock not working (disabled?)

saepien, 2023-06-14:
### Subject of the issue

config-security-lock isn't working
After setting config-security-lock in non-volatile memory (BDR) all configuration on the M10 should be permanently locked. Device should always power up to the locked configuration and it should no longer be possible to change it.

My concern is that these feature has been somehow disabled in the hardware?
The devices are useless if they cannot reliably maintain operating config

### Your workbench
Using a Mac with U-Center 2 ver. 22.10.39687
Per U-Blox recommendation (U-Center 1.0 not recommended for 10-gen modules)

### Steps to reproduce
See attached screenshot.

Suggest you change baud rate setting and some NMEA outputs, write to device. Then send config values from the screenshot to the device. Reboot device several times over 1 hour period.

### Expected behavior
Device should default to the saved config values and it should no longer be possible to write new config values to the device.

### Actual behavior
No change at all.
Device does not lock. It remains possible to update config values.
Also, after powering down/up the device (possibly more than once) it tends to revert back to default values (so 9600 bauds, all NMEA messages, all interfaces, etc)

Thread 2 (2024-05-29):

Docs - Bad hyperlink

santaimpersonator, 2024-05-29:
There is an incorrect product link in this [section](https://docs.sparkfun.com/SparkFun_u-blox_SAM-M10Q/hardware_overview/#plated-through-hole-headers) of the hardware overview:
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

Looks like the link just needs to be added here:
https://github.com/sparkfun/SparkFun_u-blox_SAM-M10Q/blob/d886846b7572d3635691e711028dcbe2416bee81/docs/hardware_overview.md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

### Expected behavior
Should link to product: https://www.sparkfun.com/products/15096

### Actual behavior
Links to page: https://docs.sparkfun.com/SparkFun_u-blox_SAM-M10Q/hardware_overview/

bboyho, 2024-06-04:
Merged the docs branch and updated the link. The markdown to link the product was empty so it defaulted to pointing back to the page. =)

Closed 2024-06-04.

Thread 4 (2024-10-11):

Help to configure M10Q over serial

richonguzman, 2024-10-11:
I have Lilygo T-Deck Plus board with has M10Q GPS board mounted but has its output as UBLOX defined (I guess)

I found code to send over Serial to the GPS and change it to NMEA output.

But I read the M10Q has GNSS and should get easy more than 10-11 sats as another GNSS board I have here.

is there commands available to enable it this full GNSS way?

i paste here the commands used:

`
bool M10Q_GPS_Init() {
    uint8_t cfg_clear1[] = {0xB5, 0x62, 0x06, 0x09, 0x0D, 0x00, 0xFF, 0xFF, 0x00, 0x00, 0x00, 0x00, 0x00, 0x00, 0x00, 0x00, 0x00, 0x00, 0x02, 0x1C, 0xA2};
    uint8_t cfg_clear2[] = {0xB5, 0x62, 0x06, 0x09, 0x0D, 0x00, 0xFF, 0xFF, 0x00, 0x00, 0x00, 0x00, 0x00, 0x00, 0x00, 0x00, 0x00, 0x00, 0x01, 0x1B, 0xA1};
    uint8_t cfg_clear3[] = {0xB5, 0x62, 0x06, 0x09, 0x0D, 0x00, 0x00, 0x00, 0x00, 0x00, 0x00, 0x00, 0x00, 0x00, 0xFF, 0xFF, 0x00, 0x00, 0x03, 0x1D, 0xB3};
    gpsSerial.write(cfg_clear1, sizeof(cfg_clear1));

    if (getAck(buffer, 256, 0x05, 0x01)) {
        Serial.println("Get ack successes!");
    }
    gpsSerial.write(cfg_clear2, sizeof(cfg_clear2));
    if (getAck(buffer, 256, 0x05, 0x01)) {
        Serial.println("Get ack successes!");
    }
    gpsSerial.write(cfg_clear3, sizeof(cfg_clear3));
    if (getAck(buffer, 256, 0x05, 0x01)) {
        Serial.println("Get ack successes!");
    }

    // UBX-CFG-RATE, Size 8, 'Navigation/measurement rate settings'
    uint8_t cfg_rate[] = {0xB5, 0x62, 0x06, 0x08, 0x00, 0x00, 0x0E, 0x30};
    gpsSerial.write(cfg_rate, sizeof(cfg_rate));
    if (getAck(buffer, 256, 0x06, 0x08)) {
        Serial.println("Get ack successes!");
    } else {
        return false;
    }
    return true;
}
`

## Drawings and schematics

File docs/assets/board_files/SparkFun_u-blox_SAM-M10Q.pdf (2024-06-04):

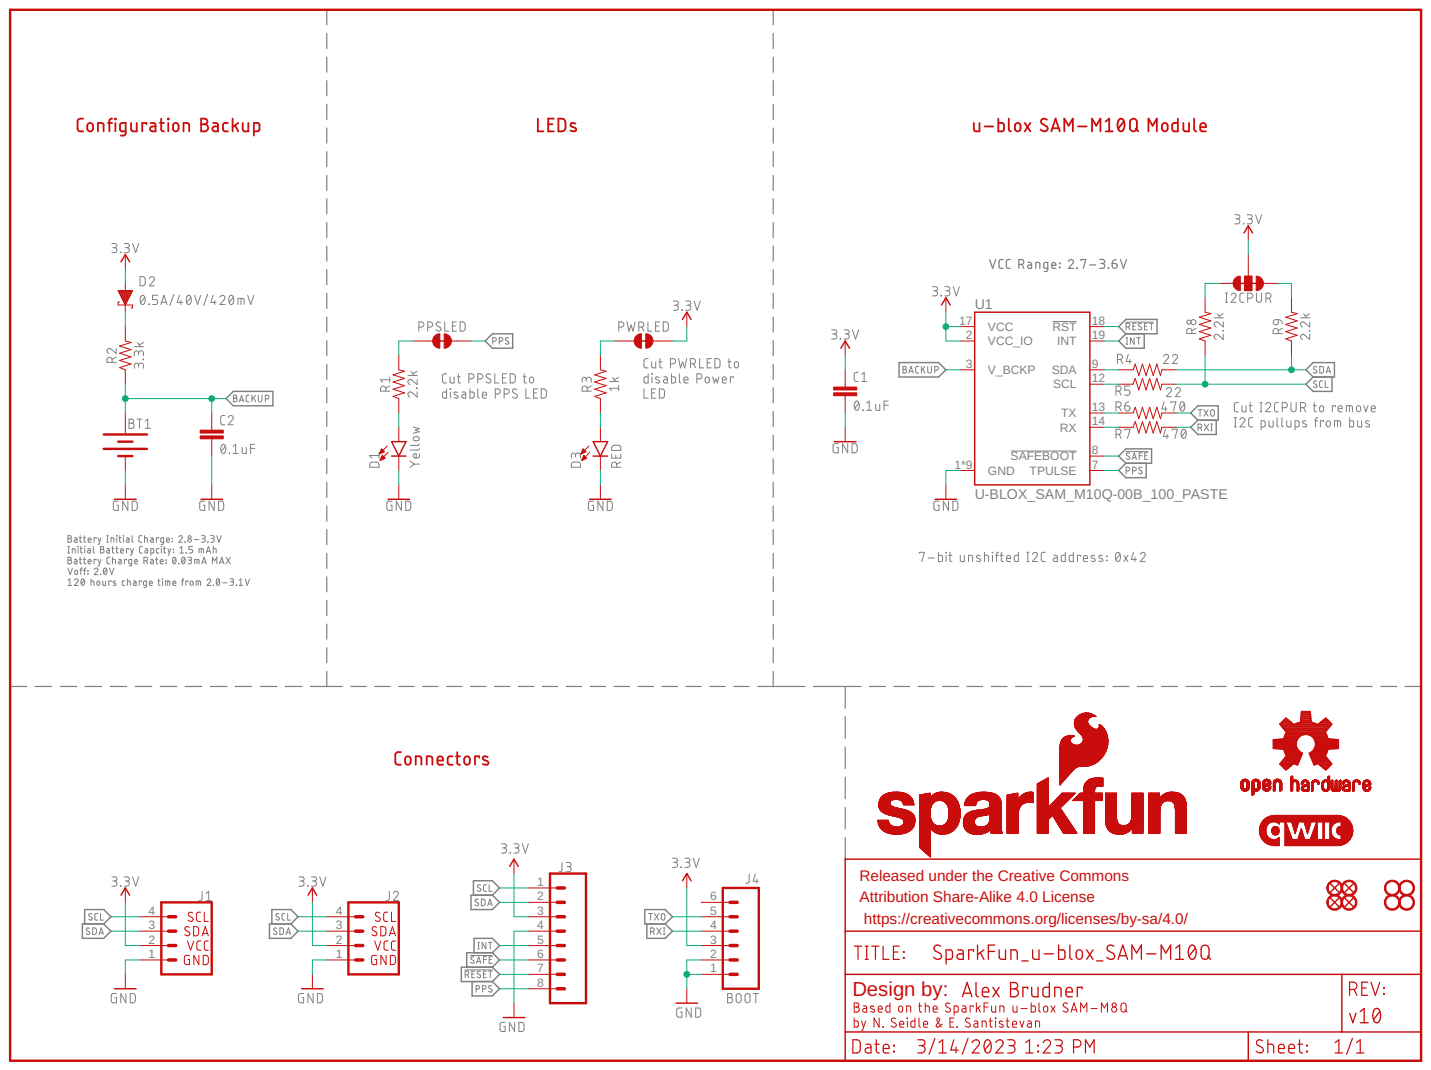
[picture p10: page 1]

Released under the Creative Commons Attribution Share-Alike 4.0 License

https://creativecommons.org/licenses/by-sa/4.0/

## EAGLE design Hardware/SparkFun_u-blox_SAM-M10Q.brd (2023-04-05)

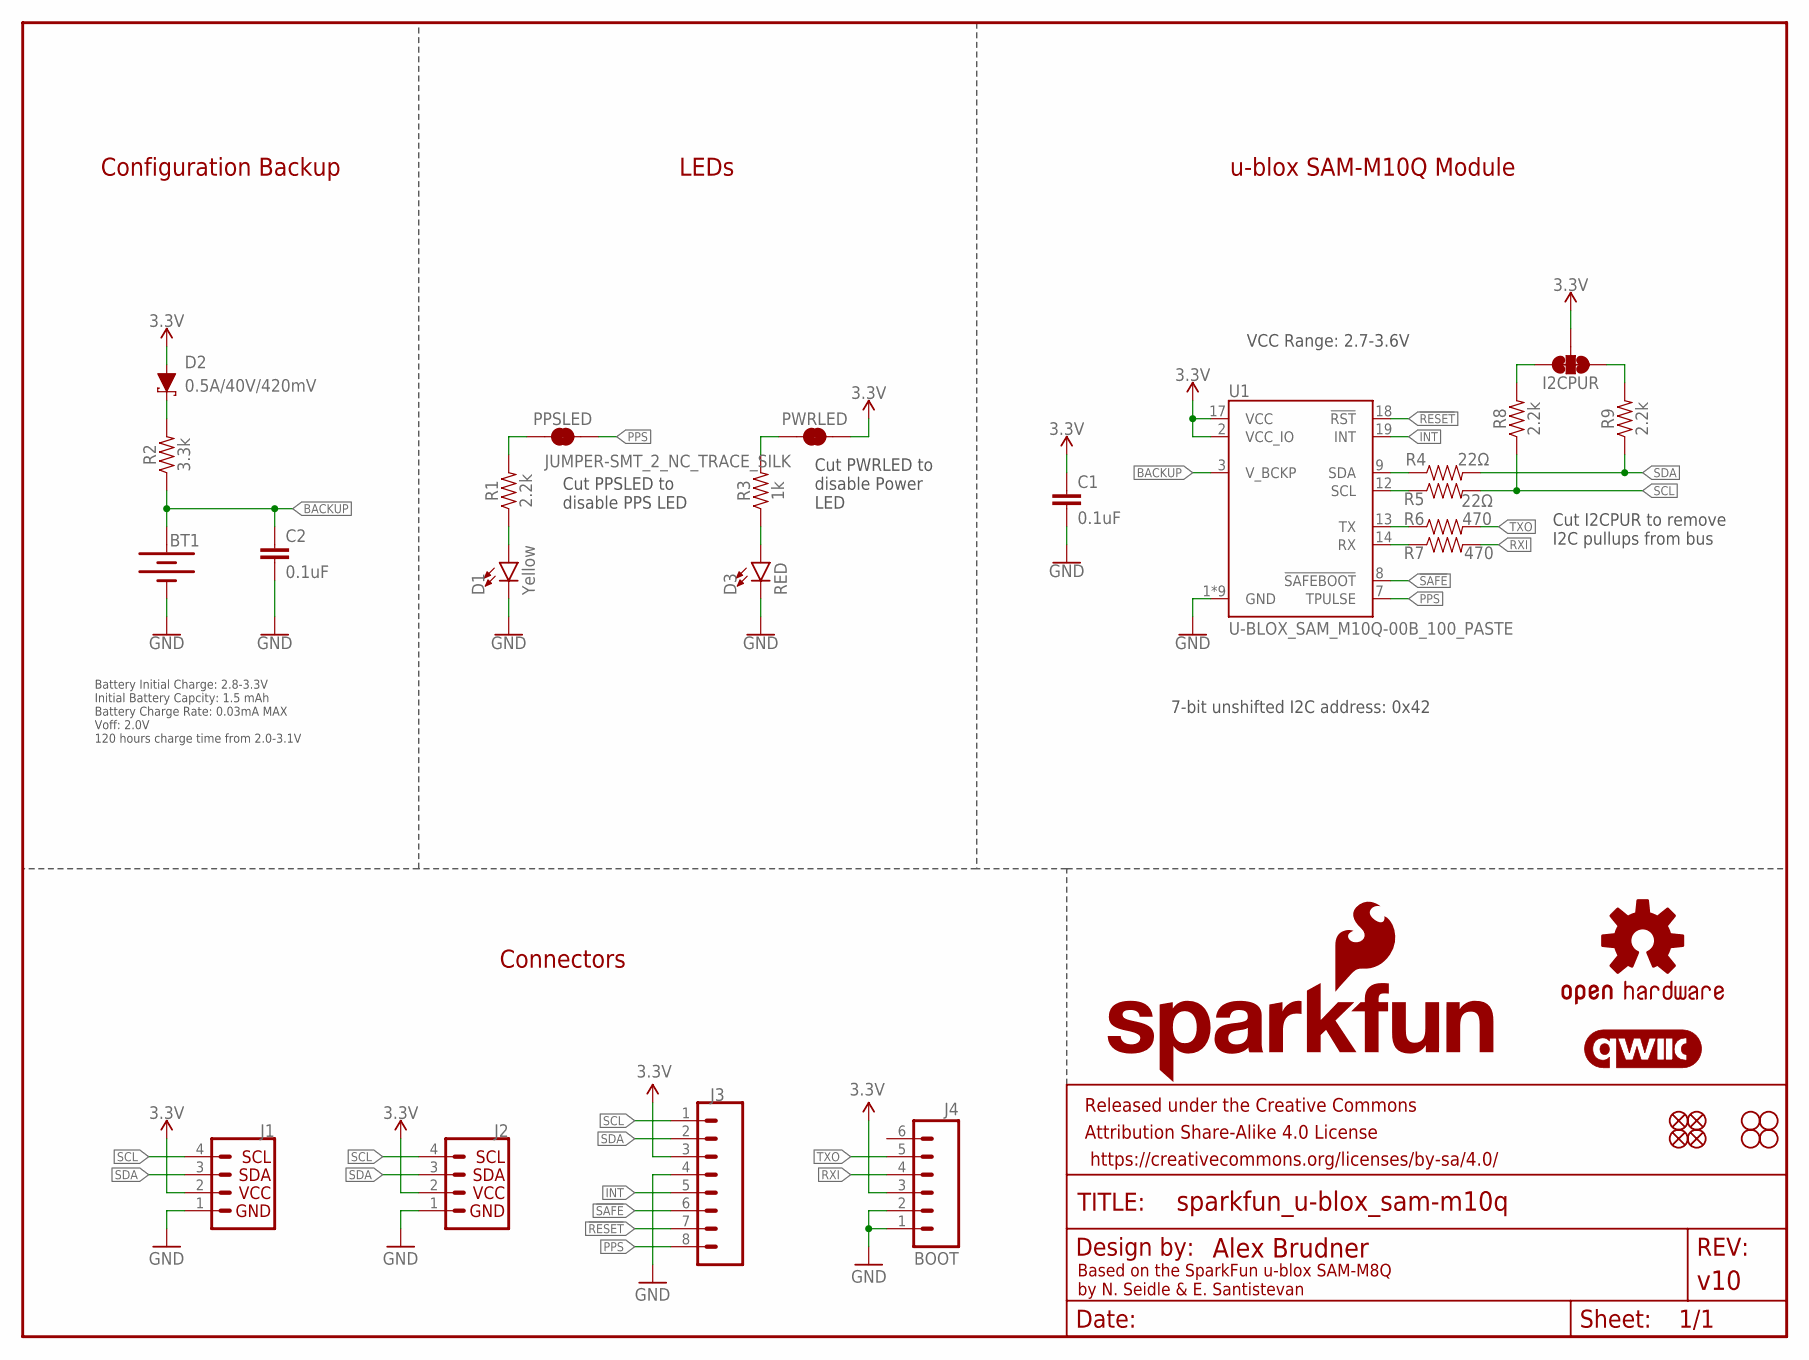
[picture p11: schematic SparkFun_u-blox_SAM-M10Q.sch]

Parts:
BT1: 6.8MM_COIN_CELL; MS421R_IV03E
C1, C2: 0.1uF; 0603
D1: Yellow; LED-0603
D2: 0.5A/40V/420mV; SOD-323
D3: RED; LED-0603
FD1, FD2, FD3, FD4: FIDUCIALUFIDUCIAL; FIDUCIAL-MICRO
FRAME1: FRAME-LETTER; CREATIVE_COMMONS
H1, H2, H3, H4: STAND-OFF
I2CPUR: JUMPER-SMT_3_2-NC_TRACE_SILK; SMT-JUMPER_3_2-NC_TRACE_SILK
J1, J2: Qwiic Right Angle; JST04_1MM_RA
J3: CONN_08NO_SILK_FEMALE_PTH; 1X08_NO_SILK
J4: BOOT; 1X06_NO_SILK
LOGO1: OSHW-LOGOM; OSHW-LOGO-M
LOGO2: SFE_LOGO_NAME_FLAME.2_INCH; SFE_LOGO_NAME_FLAME_.2
LOGO3: QWIIC_LOGO_CONNECTOR; QWIIC_5.5MM
PPSLED: JUMPER-SMT_2_NC_TRACE_SILK; SMT-JUMPER_2_NC_TRACE_SILK
PWRLED: JUMPER-SMT_2_NC_TRACE_SILK; SMT-JUMPER_2_NC_TRACE_SILK
R1, R8, R9: 2.2k; 0603
R2: 3.3k; 0603
R3: 1k; 0603
R4, R5: 22Ω; 0603
R6, R7: 470; 0603
U1: U-BLOX_SAM_M10Q-00B_100_PASTE; SAM-M10Q_100PASTE

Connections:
3.3V: C1.1, D2.A, I2CPUR.2, J1.2, J2.2, J3.3, J4.3, PWRLED.2, U1.2 (VCC_IO), U1.17 (VCC)
!RESET: J3.7, U1.18 (!RST)
!SAFE: J3.6, U1.8 (!SAFEBOOT)
BACKUP: BT1.+, C2.1, R2.1, U1.3 (V_BCKP)
GND: BT1.-, C1.2, C2.2, D1.C, D3.C, J1.1, J2.1, J3.4, J4.1, J4.2, U1.1 (GND), U1.4 (GND), U1.5 (GND), U1.6 (GND), U1.10 (GND), U1.11 (GND), U1.15 (GND), U1.16 (GND), U1.20 (GND)
INT: J3.5, U1.19 (INT)
unnamed: PWRLED.1, R3.2
unnamed: D1.A, R1.1
unnamed: D3.A, R3.1
unnamed: PPSLED.1, R1.2
unnamed: I2CPUR.1, R9.2
unnamed: D2.C, R2.2
unnamed: I2CPUR.3, R8.2
PPS: J3.8, PPSLED.2, U1.7 (TPULSE)
RXI: J4.4, R7.2
RXLV: R7.1, U1.14 (RX)
SCL: J1.4, J2.4, J3.1, R5.2, R8.1
SCL_LV: R5.1, U1.12 (SCL)
SDA: J1.3, J2.3, J3.2, R4.2, R9.1
SDA_LV: R4.1, U1.9 (SDA)
TXLV: R6.1, U1.13 (TX)
TXO: J4.5, R6.2

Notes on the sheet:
Based on the SparkFun u-blox SAM-M8Q by N. Seidle & E. Santistevan
Battery Initial Charge: 2.8-3.3V Initial Battery Capcity: 1.5 mAh Battery Charge Rate: 0.03mA MAX Voff: 2.0V 120 hours charge time from 2.0-3.1V
7-bit unshifted I2C address: 0x42
Cut I2CPUR to remove I2C pullups from bus
VCC Range: 2.7-3.6V
LEDs
Cut PPSLED to disable PPS LED
Cut PWRLED to disable Power LED
Configuration Backup
u-blox SAM-M10Q Module
Connectors

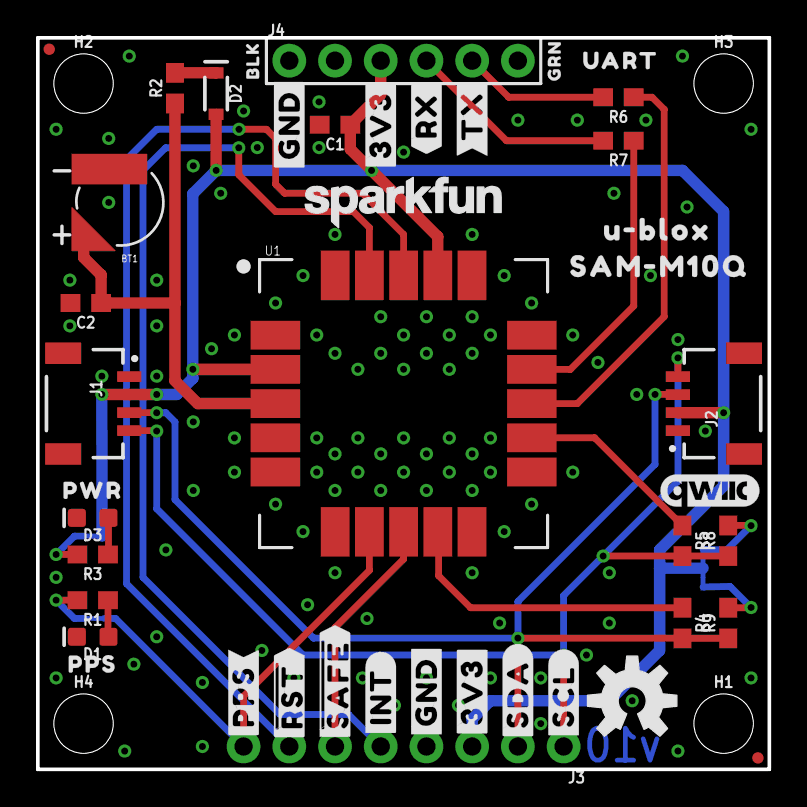
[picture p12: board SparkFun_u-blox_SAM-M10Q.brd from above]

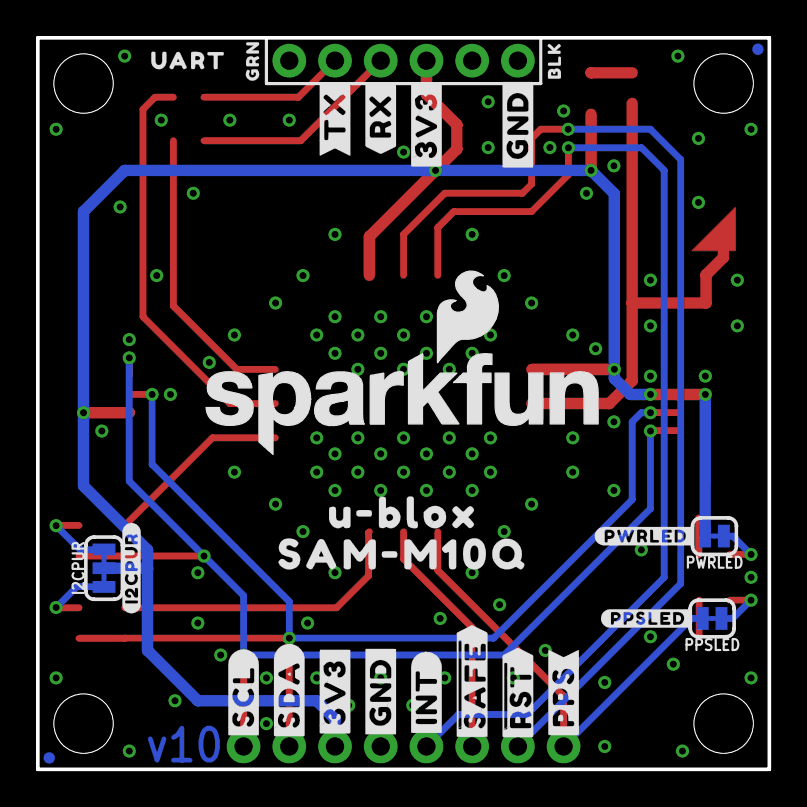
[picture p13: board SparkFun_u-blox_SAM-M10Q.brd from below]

Board: 2 copper layers, 40.6 x 40.6 mm, 76 parts (26 on the bottom side), 22 nets.

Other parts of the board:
U$1: SFE_LOGO_FLAME_STOP_.1
U$2: SAM#M10Q11
U$3, U$4: BLK4
U$5, U$6: GRN5
U$7, U$8: UART7
U$9: PPS9
U$10: PWR10
U$11, U$12: #TX#12
U$13, U$14: #RX#13
U$15, U$16, U$22, U$23: #3V3#0
U$17, U$20: #GND#4
U$18: U#BLOX11
U$19, U$21: #GND#5
U$24, U$25: #SCL#6
U$26, U$27: #SDA#7
U$28, U$29: #INT#8
U$30, U$33: ##RST##15
U$31: SFE_LOGO_NAME_.1
U$32: SAM#M10Q12
U$34, U$35: #PPS#13
U$36, U$37: ##SAFE##16
U$38: U#BLOX12
U$40: #PPSLED#0
U$41: #I2CPUR#0
U$42: #PWRLED#0

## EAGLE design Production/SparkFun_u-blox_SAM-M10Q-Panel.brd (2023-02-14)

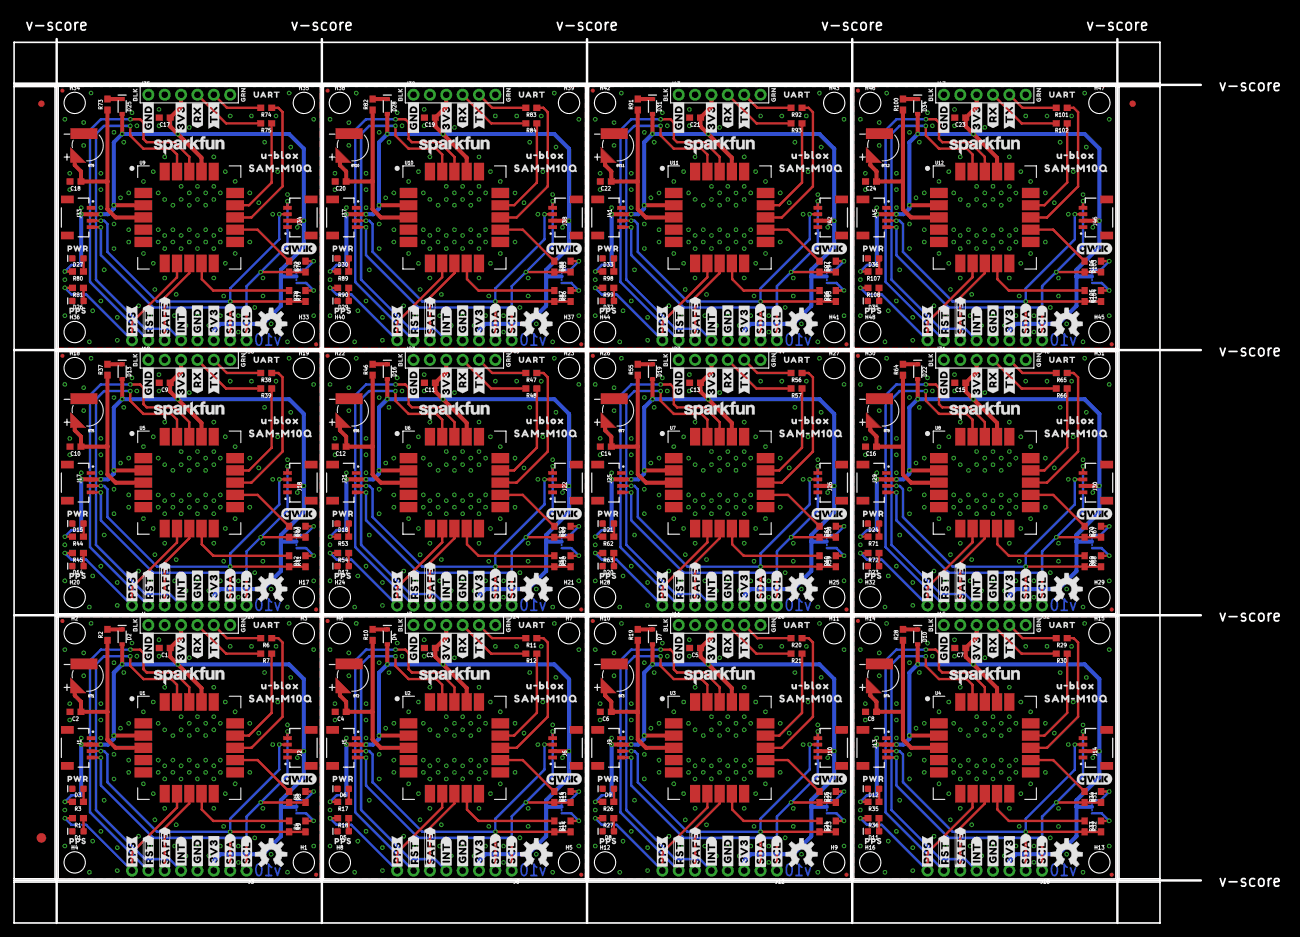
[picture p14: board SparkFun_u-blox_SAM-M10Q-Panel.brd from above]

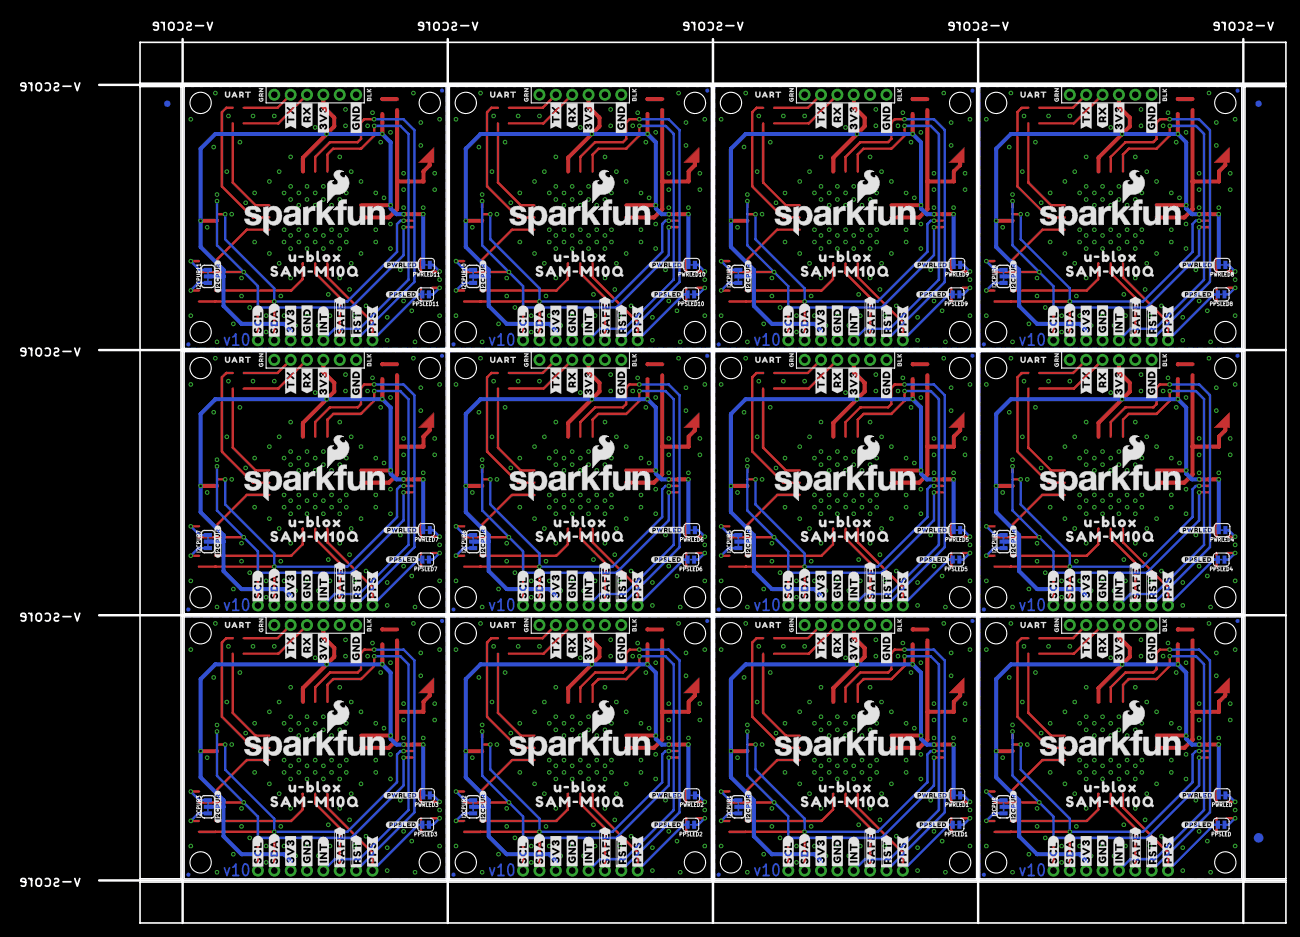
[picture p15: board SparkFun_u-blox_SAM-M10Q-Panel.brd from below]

Board: 2 copper layers, 184.2 x 137.2 mm, 906 parts (315 on the bottom side), 264 nets.

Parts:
BT1, BT2, BT3, BT4, BT5, BT6, BT7, BT8, BT9, BT10, BT11, BT12: 6.8MM_COIN_CELL; MS421R_IV03E
C1, C2, C3, C4, C5, C6, C7, C8, C9, C10, C11, C12, C13, C14, C15, C16, C17, C18, C19, C20, C21, C22, C23, C24: 0.1uF; 0603
D1, D5, D8, D11, D14, D17, D20, D23, D26, D29, D32, D35: Yellow; LED-0603
D2, D4, D7, D10, D13, D16, D19, D22, D25, D28, D31, D34: 0.5A/40V/420mV; SOD-323
D3, D6, D9, D12, D15, D18, D21, D24, D27, D30, D33, D36: RED; LED-0603
E$1, E$2, E$3, E$4: FIDUCIAL-1X2
E$5, E$6: FIDUCIAL-1.5X3
FD1, FD2, FD3, FD4, FD5, FD6, FD7, FD8, FD9, FD10, FD11, FD12, FD13, FD14, FD15, FD16, FD17, FD18, FD19, FD20, FD21, FD22, FD23, FD24, FD25, FD26, FD27, FD28, FD29, FD30, FD31, FD32, FD33, FD34, FD35, FD36, FD37, FD38, FD39, FD40, FD41, FD42, FD43, FD44, FD45, FD46, FD47, FD48: FIDUCIALUFIDUCIAL; FIDUCIAL-MICRO
H1, H2, H3, H4, H5, H6, H7, H8, H9, H10, H11, H12, H13, H14, H15, H16, H17, H18, H19, H20, H21, H22, H23, H24, H25, H26, H27, H28, H29, H30, H31, H32, H33, H34, H35, H36, H37, H38, H39, H40, H41, H42, H43, H44, H45, H46, H47, H48: STAND-OFF
I2CPUR, I2CPUR1, I2CPUR2, I2CPUR3, I2CPUR4, I2CPUR5, I2CPUR6, I2CPUR7, I2CPUR8, I2CPUR9, I2CPUR10, I2CPUR11: JUMPER-SMT_3_2-NC_TRACE_SILK; SMT-JUMPER_3_2-NC_TRACE_SILK
J1, J2, J5, J6, J9, J10, J13, J14, J17, J18, J21, J22, J25, J26, J29, J30, J33, J34, J37, J38, J41, J42, J45, J46: Qwiic Right Angle; JST04_1MM_RA
J3, J8, J12, J16, J20, J24, J28, J32, J36, J40, J44, J48: 1X08_NO_SILK
J4, J7, J11, J15, J19, J23, J27, J31, J35, J39, J43, J47: BOOT; 1X06_NO_SILK
LOGO1, LOGO4, LOGO7, LOGO10, LOGO13, LOGO16, LOGO19, LOGO22, LOGO25, LOGO28, LOGO31, LOGO34: OSHW-LOGOM; OSHW-LOGO-M
LOGO2, LOGO5, LOGO8, LOGO11, LOGO14, LOGO17, LOGO20, LOGO23, LOGO26, LOGO29, LOGO32, LOGO35: SFE_LOGO_NAME_FLAME.2_INCH; SFE_LOGO_NAME_FLAME_.2
LOGO3, LOGO6, LOGO9, LOGO12, LOGO15, LOGO18, LOGO21, LOGO24, LOGO27, LOGO30, LOGO33, LOGO36: QWIIC_LOGO_CONNECTOR; QWIIC_5.5MM
PPSLED, PPSLED1, PPSLED2, PPSLED3, PPSLED4, PPSLED5, PPSLED6, PPSLED7, PPSLED8, PPSLED9, PPSLED10, PPSLED11: SMT-JUMPER_2_NC_TRACE_SILK
PWRLED, PWRLED1, PWRLED2, PWRLED3, PWRLED4, PWRLED5, PWRLED6, PWRLED7, PWRLED8, PWRLED9, PWRLED10, PWRLED11: JUMPER-SMT_2_NC_TRACE_SILK; SMT-JUMPER_2_NC_TRACE_SILK
R1, R8, R9, R13, R14, R18, R22, R23, R27, R31, R32, R36, R40, R41, R45, R49, R50, R54, R58, R59, R63, R67, R68, R72, R76, R77, R81, R85, R86, R90, R94, R95, R99, R103, R104, R108: 2.2k; 0603
R2, R10, R19, R28, R37, R46, R55, R64, R73, R82, R91, R100: 3.3k; 0603
R3, R17, R26, R35, R44, R53, R62, R71, R80, R89, R98, R107: 1k; 0603
R4, R5, R15, R16, R24, R25, R33, R34, R42, R43, R51, R52, R60, R61, R69, R70, R78, R79, R87, R88, R96, R97, R105, R106: 22; 0603
R6, R7, R11, R12, R20, R21, R29, R30, R38, R39, R47, R48, R56, R57, R65, R66, R74, R75, R83, R84, R92, R93, R101, R102: 470; 0603
U1, U2, U3, U4, U5, U6, U7, U8, U9, U10, U11, U12: U-BLOX_SAM_M10Q-00B; SAM-M10Q
U$1, U$39, U$83, U$124, U$165, U$206, U$247, U$288, U$329, U$370, U$411, U$452: SFE_LOGO_FLAME_STOP_.1
U$2, U$79, U$120, U$161, U$202, U$243, U$284, U$325, U$366, U$407, U$448, U$489: SAM#M10Q11
U$3, U$4, U$43, U$44, U$84, U$85, U$125, U$126, U$166, U$167, U$207, U$208, U$248, U$249, U$289, U$290, U$330, U$331, U$371, U$372, U$412, U$413, U$453, U$454: BLK4
U$5, U$6, U$45, U$46, U$86, U$87, U$127, U$128, U$168, U$169, U$209, U$210, U$250, U$251, U$291, U$292, U$332, U$333, U$373, U$374, U$414, U$415, U$455, U$456: GRN5
U$7, U$8, U$47, U$48, U$88, U$89, U$129, U$130, U$170, U$171, U$211, U$212, U$252, U$253, U$293, U$294, U$334, U$335, U$375, U$376, U$416, U$417, U$457, U$458: UART7
U$9, U$49, U$90, U$131, U$172, U$213, U$254, U$295, U$336, U$377, U$418, U$459: PPS9
U$10, U$50, U$91, U$132, U$173, U$214, U$255, U$296, U$337, U$378, U$419, U$460: PWR10
U$11, U$12, U$51, U$52, U$92, U$93, U$133, U$134, U$174, U$175, U$215, U$216, U$256, U$257, U$297, U$298, U$338, U$339, U$379, U$380, U$420, U$421, U$461, U$462: #TX#12
U$13, U$14, U$53, U$54, U$94, U$95, U$135, U$136, U$176, U$177, U$217, U$218, U$258, U$259, U$299, U$300, U$340, U$341, U$381, U$382, U$422, U$423, U$463, U$464: #RX#13
U$15, U$16, U$22, U$23, U$55, U$56, U$61, U$62, U$96, U$97, U$102, U$103, U$137, U$138, U$143, U$144, U$178, U$179, U$184, U$185, U$219, U$220, U$225, U$226, U$260, U$261, U$266, U$267, U$301, U$302, U$307, U$308, U$342, U$343, U$348, U$349, U$383, U$384, U$389, U$390, U$424, U$425, U$430, U$431, U$465, U$466, U$471, U$472: #3V3#0
U$17, U$20, U$57, U$58, U$98, U$99, U$139, U$140, U$180, U$181, U$221, U$222, U$262, U$263, U$303, U$304, U$344, U$345, U$385, U$386, U$426, U$427, U$467, U$468: #GND#4
U$18, U$80, U$121, U$162, U$203, U$244, U$285, U$326, U$367, U$408, U$449, U$490: U#BLOX11
U$19, U$21, U$59, U$60, U$100, U$101, U$141, U$142, U$182, U$183, U$223, U$224, U$264, U$265, U$305, U$306, U$346, U$347, U$387, U$388, U$428, U$429, U$469, U$470: #GND#5
U$24, U$25, U$63, U$64, U$104, U$105, U$145, U$146, U$186, U$187, U$227, U$228, U$268, U$269, U$309, U$310, U$350, U$351, U$391, U$392, U$432, U$433, U$473, U$474: #SCL#6
U$26, U$27, U$65, U$66, U$106, U$107, U$147, U$148, U$188, U$189, U$229, U$230, U$270, U$271, U$311, U$312, U$352, U$353, U$393, U$394, U$434, U$435, U$475, U$476: #SDA#7
U$28, U$29, U$67, U$68, U$108, U$109, U$149, U$150, U$190, U$191, U$231, U$232, U$272, U$273, U$313, U$314, U$354, U$355, U$395, U$396, U$436, U$437, U$477, U$478: #INT#8
U$30, U$33, U$71, U$72, U$112, U$113, U$153, U$154, U$194, U$195, U$235, U$236, U$276, U$277, U$317, U$318, U$358, U$359, U$399, U$400, U$440, U$441, U$481, U$482: ##RST##15
U$31, U$75, U$116, U$157, U$198, U$239, U$280, U$321, U$362, U$403, U$444, U$485: SFE_LOGO_NAME_.1
U$32, U$81, U$122, U$163, U$204, U$245, U$286, U$327, U$368, U$409, U$450, U$491: SAM#M10Q12
U$34, U$35, U$69, U$70, U$110, U$111, U$151, U$152, U$192, U$193, U$233, U$234, U$274, U$275, U$315, U$316, U$356, U$357, U$397, U$398, U$438, U$439, U$479, U$480: #PPS#13
U$36, U$37, U$73, U$74, U$114, U$115, U$155, U$156, U$196, U$197, U$237, U$238, U$278, U$279, U$319, U$320, U$360, U$361, U$401, U$402, U$442, U$443, U$483, U$484: ##SAFE##16
U$38, U$82, U$123, U$164, U$205, U$246, U$287, U$328, U$369, U$410, U$451, U$492: U#BLOX12
U$40, U$77, U$118, U$159, U$200, U$241, U$282, U$323, U$364, U$405, U$446, U$487: #PPSLED#0
U$41, U$78, U$119, U$160, U$201, U$242, U$283, U$324, U$365, U$406, U$447, U$488: #I2CPUR#0
U$42, U$76, U$117, U$158, U$199, U$240, U$281, U$322, U$363, U$404, U$445, U$486: #PWRLED#0

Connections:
3.3V: C1.1, D2.A, I2CPUR.2, J1.2, J2.2, J3.3, J4.3, PWRLED.2, U1.2, U1.17
3.3V1: C3.1, D4.A, I2CPUR1.2, J5.2, J6.2, J7.3, J8.3, PWRLED1.2, U2.2, U2.17
3.3V2: C5.1, D7.A, I2CPUR2.2, J9.2, J10.2, J11.3, J12.3, PWRLED2.2, U3.2, U3.17
3.3V3: C7.1, D10.A, I2CPUR3.2, J13.2, J14.2, J15.3, J16.3, PWRLED3.2, U4.2, U4.17
3.3V4: C9.1, D13.A, I2CPUR4.2, J17.2, J18.2, J19.3, J20.3, PWRLED4.2, U5.2, U5.17
3.3V5: C11.1, D16.A, I2CPUR5.2, J21.2, J22.2, J23.3, J24.3, PWRLED5.2, U6.2, U6.17
3.3V6: C13.1, D19.A, I2CPUR6.2, J25.2, J26.2, J27.3, J28.3, PWRLED6.2, U7.2, U7.17
3.3V7: C15.1, D22.A, I2CPUR7.2, J29.2, J30.2, J31.3, J32.3, PWRLED7.2, U8.2, U8.17
3.3V8: C17.1, D25.A, I2CPUR8.2, J33.2, J34.2, J35.3, J36.3, PWRLED8.2, U9.2, U9.17
3.3V9: C19.1, D28.A, I2CPUR9.2, J37.2, J38.2, J39.3, J40.3, PWRLED9.2, U10.2, U10.17
3.3V10: C21.1, D31.A, I2CPUR10.2, J41.2, J42.2, J43.3, J44.3, PWRLED10.2, U11.2, U11.17
3.3V11: C23.1, D34.A, I2CPUR11.2, J45.2, J46.2, J47.3, J48.3, PWRLED11.2, U12.2, U12.17
!RESET: J3.7, U1.18
!RESET1: J8.7, U2.18
!RESET2: J12.7, U3.18
!RESET3: J16.7, U4.18
!RESET4: J20.7, U5.18
!RESET5: J24.7, U6.18
!RESET6: J28.7, U7.18
!RESET7: J32.7, U8.18
!RESET8: J36.7, U9.18
!RESET9: J40.7, U10.18
!RESET10: J44.7, U11.18
!RESET11: J48.7, U12.18
!SAFE: J3.6, U1.8
!SAFE1: J8.6, U2.8
!SAFE2: J12.6, U3.8
!SAFE3: J16.6, U4.8
!SAFE4: J20.6, U5.8
!SAFE5: J24.6, U6.8
!SAFE6: J28.6, U7.8
!SAFE7: J32.6, U8.8
!SAFE8: J36.6, U9.8
!SAFE9: J40.6, U10.8
!SAFE10: J44.6, U11.8
!SAFE11: J48.6, U12.8
BACKUP: BT1.+, C2.1, R2.1, U1.3
BACKUP1: BT2.+, C4.1, R10.1, U2.3
BACKUP2: BT3.+, C6.1, R19.1, U3.3
BACKUP3: BT4.+, C8.1, R28.1, U4.3
BACKUP4: BT5.+, C10.1, R37.1, U5.3
BACKUP5: BT6.+, C12.1, R46.1, U6.3
BACKUP6: BT7.+, C14.1, R55.1, U7.3
BACKUP7: BT8.+, C16.1, R64.1, U8.3
BACKUP8: BT9.+, C18.1, R73.1, U9.3
BACKUP9: BT10.+, C20.1, R82.1, U10.3
BACKUP10: BT11.+, C22.1, R91.1, U11.3
BACKUP11: BT12.+, C24.1, R100.1, U12.3
GND: BT1.-, C1.2, C2.2, D1.C, D3.C, J1.1, J2.1, J3.4, J4.1, J4.2, U1.1, U1.4, U1.5, U1.6, U1.10, U1.11, U1.15, U1.16, U1.20
GND1: BT2.-, C3.2, C4.2, D5.C, D6.C, J5.1, J6.1, J7.1, J7.2, J8.4, U2.1, U2.4, U2.5, U2.6, U2.10, U2.11, U2.15, U2.16, U2.20
GND2: BT3.-, C5.2, C6.2, D8.C, D9.C, J9.1, J10.1, J11.1, J11.2, J12.4, U3.1, U3.4, U3.5, U3.6, U3.10, U3.11, U3.15, U3.16, U3.20
GND3: BT4.-, C7.2, C8.2, D11.C, D12.C, J13.1, J14.1, J15.1, J15.2, J16.4, U4.1, U4.4, U4.5, U4.6, U4.10, U4.11, U4.15, U4.16, U4.20
GND4: BT5.-, C9.2, C10.2, D14.C, D15.C, J17.1, J18.1, J19.1, J19.2, J20.4, U5.1, U5.4, U5.5, U5.6, U5.10, U5.11, U5.15, U5.16, U5.20
GND5: BT6.-, C11.2, C12.2, D17.C, D18.C, J21.1, J22.1, J23.1, J23.2, J24.4, U6.1, U6.4, U6.5, U6.6, U6.10, U6.11, U6.15, U6.16, U6.20
GND6: BT7.-, C13.2, C14.2, D20.C, D21.C, J25.1, J26.1, J27.1, J27.2, J28.4, U7.1, U7.4, U7.5, U7.6, U7.10, U7.11, U7.15, U7.16, U7.20
GND7: BT8.-, C15.2, C16.2, D23.C, D24.C, J29.1, J30.1, J31.1, J31.2, J32.4, U8.1, U8.4, U8.5, U8.6, U8.10, U8.11, U8.15, U8.16, U8.20
GND8: BT9.-, C17.2, C18.2, D26.C, D27.C, J33.1, J34.1, J35.1, J35.2, J36.4, U9.1, U9.4, U9.5, U9.6, U9.10, U9.11, U9.15, U9.16, U9.20
GND9: BT10.-, C19.2, C20.2, D29.C, D30.C, J37.1, J38.1, J39.1, J39.2, J40.4, U10.1, U10.4, U10.5, U10.6, U10.10, U10.11, U10.15, U10.16, U10.20
GND10: BT11.-, C21.2, C22.2, D32.C, D33.C, J41.1, J42.1, J43.1, J43.2, J44.4, U11.1, U11.4, U11.5, U11.6, U11.10, U11.11, U11.15, U11.16, U11.20
GND11: BT12.-, C23.2, C24.2, D35.C, D36.C, J45.1, J46.1, J47.1, J47.2, J48.4, U12.1, U12.4, U12.5, U12.6, U12.10, U12.11, U12.15, U12.16, U12.20
INT: J3.5, U1.19
INT1: J8.5, U2.19
INT2: J12.5, U3.19
INT3: J16.5, U4.19
INT4: J20.5, U5.19
INT5: J24.5, U6.19
INT6: J28.5, U7.19
INT7: J32.5, U8.19
INT8: J36.5, U9.19
INT9: J40.5, U10.19
INT10: J44.5, U11.19
INT11: J48.5, U12.19
unnamed: PWRLED.1, R3.2
unnamed: D1.A, R1.1
unnamed: D3.A, R3.1
unnamed: PPSLED.1, R1.2
unnamed: I2CPUR.1, R9.2
unnamed: D2.C, R2.2
unnamed: D4.C, R10.2
unnamed: I2CPUR.3, R8.2
unnamed: I2CPUR1.1, R14.2
unnamed: I2CPUR1.3, R13.2
unnamed: D5.A, R18.1
unnamed: PPSLED1.1, R18.2
unnamed: PWRLED1.1, R17.2
unnamed: D6.A, R17.1
unnamed: D7.C, R19.2
unnamed: I2CPUR2.1, R23.2
unnamed: I2CPUR2.3, R22.2
unnamed: D8.A, R27.1
unnamed: PPSLED2.1, R27.2
unnamed: PWRLED2.1, R26.2
unnamed: D9.A, R26.1
unnamed: D10.C, R28.2
unnamed: I2CPUR3.1, R32.2
unnamed: I2CPUR3.3, R31.2
unnamed: D11.A, R36.1
unnamed: PPSLED3.1, R36.2
unnamed: PWRLED3.1, R35.2
unnamed: D12.A, R35.1
unnamed: D13.C, R37.2
unnamed: I2CPUR4.1, R41.2
unnamed: I2CPUR4.3, R40.2
unnamed: D14.A, R45.1
unnamed: PPSLED4.1, R45.2
unnamed: PWRLED4.1, R44.2
unnamed: D15.A, R44.1
unnamed: D16.C, R46.2
unnamed: I2CPUR5.1, R50.2
unnamed: I2CPUR5.3, R49.2
unnamed: D17.A, R54.1
unnamed: PPSLED5.1, R54.2
unnamed: PWRLED5.1, R53.2
unnamed: D18.A, R53.1
unnamed: D19.C, R55.2
unnamed: I2CPUR6.1, R59.2
unnamed: I2CPUR6.3, R58.2
unnamed: D20.A, R63.1
unnamed: PPSLED6.1, R63.2
unnamed: PWRLED6.1, R62.2
unnamed: D21.A, R62.1
unnamed: D22.C, R64.2
unnamed: I2CPUR7.1, R68.2
unnamed: I2CPUR7.3, R67.2
unnamed: D23.A, R72.1
unnamed: PPSLED7.1, R72.2
unnamed: PWRLED7.1, R71.2
unnamed: D24.A, R71.1
unnamed: D25.C, R73.2
unnamed: I2CPUR8.1, R77.2
unnamed: I2CPUR8.3, R76.2
unnamed: D26.A, R81.1
unnamed: PPSLED8.1, R81.2
unnamed: PWRLED8.1, R80.2
unnamed: D27.A, R80.1
unnamed: D28.C, R82.2
unnamed: I2CPUR9.1, R86.2
unnamed: I2CPUR9.3, R85.2
unnamed: D29.A, R90.1
unnamed: PPSLED9.1, R90.2
unnamed: PWRLED9.1, R89.2
unnamed: D30.A, R89.1
unnamed: D31.C, R91.2
unnamed: I2CPUR10.1, R95.2
unnamed: I2CPUR10.3, R94.2
unnamed: D32.A, R99.1
unnamed: PPSLED10.1, R99.2
unnamed: PWRLED10.1, R98.2
unnamed: D33.A, R98.1
unnamed: D34.C, R100.2
unnamed: I2CPUR11.1, R104.2
unnamed: I2CPUR11.3, R103.2
unnamed: D35.A, R108.1
unnamed: PPSLED11.1, R108.2
unnamed: PWRLED11.1, R107.2
unnamed: D36.A, R107.1
PPS: J3.8, PPSLED.2, U1.7
PPS1: J8.8, PPSLED1.2, U2.7
PPS2: J12.8, PPSLED2.2, U3.7
PPS3: J16.8, PPSLED3.2, U4.7
PPS4: J20.8, PPSLED4.2, U5.7
PPS5: J24.8, PPSLED5.2, U6.7
PPS6: J28.8, PPSLED6.2, U7.7
PPS7: J32.8, PPSLED7.2, U8.7
PPS8: J36.8, PPSLED8.2, U9.7
PPS9: J40.8, PPSLED9.2, U10.7
PPS10: J44.8, PPSLED10.2, U11.7
PPS11: J48.8, PPSLED11.2, U12.7
RXI: J4.4, R7.2
RXI1: J7.4, R12.2
RXI2: J11.4, R21.2
RXI3: J15.4, R30.2
RXI4: J19.4, R39.2
RXI5: J23.4, R48.2
RXI6: J27.4, R57.2
RXI7: J31.4, R66.2
RXI8: J35.4, R75.2
RXI9: J39.4, R84.2
RXI10: J43.4, R93.2
RXI11: J47.4, R102.2
RXLV: R7.1, U1.14
RXLV1: R12.1, U2.14
RXLV2: R21.1, U3.14
RXLV3: R30.1, U4.14
RXLV4: R39.1, U5.14
RXLV5: R48.1, U6.14
RXLV6: R57.1, U7.14
RXLV7: R66.1, U8.14
RXLV8: R75.1, U9.14
RXLV9: R84.1, U10.14
RXLV10: R93.1, U11.14
RXLV11: R102.1, U12.14
SCL: J1.4, J2.4, J3.1, R5.2, R8.1
SCL1: J5.4, J6.4, J8.1, R13.1, R16.2
SCL2: J9.4, J10.4, J12.1, R22.1, R25.2
SCL3: J13.4, J14.4, J16.1, R31.1, R34.2
SCL4: J17.4, J18.4, J20.1, R40.1, R43.2
SCL5: J21.4, J22.4, J24.1, R49.1, R52.2
SCL6: J25.4, J26.4, J28.1, R58.1, R61.2
SCL7: J29.4, J30.4, J32.1, R67.1, R70.2
SCL8: J33.4, J34.4, J36.1, R76.1, R79.2
SCL9: J37.4, J38.4, J40.1, R85.1, R88.2
SCL10: J41.4, J42.4, J44.1, R94.1, R97.2
SCL11: J45.4, J46.4, J48.1, R103.1, R106.2
SCL_LV: R5.1, U1.12
SCL_LV1: R16.1, U2.12
SCL_LV2: R25.1, U3.12
SCL_LV3: R34.1, U4.12
SCL_LV4: R43.1, U5.12
SCL_LV5: R52.1, U6.12
SCL_LV6: R61.1, U7.12
SCL_LV7: R70.1, U8.12
SCL_LV8: R79.1, U9.12
SCL_LV9: R88.1, U10.12
SCL_LV10: R97.1, U11.12
SCL_LV11: R106.1, U12.12
SDA: J1.3, J2.3, J3.2, R4.2, R9.1
SDA1: J5.3, J6.3, J8.2, R14.1, R15.2
SDA2: J9.3, J10.3, J12.2, R23.1, R24.2
SDA3: J13.3, J14.3, J16.2, R32.1, R33.2
SDA4: J17.3, J18.3, J20.2, R41.1, R42.2
SDA5: J21.3, J22.3, J24.2, R50.1, R51.2
SDA6: J25.3, J26.3, J28.2, R59.1, R60.2
SDA7: J29.3, J30.3, J32.2, R68.1, R69.2
SDA8: J33.3, J34.3, J36.2, R77.1, R78.2
SDA9: J37.3, J38.3, J40.2, R86.1, R87.2
SDA10: J41.3, J42.3, J44.2, R95.1, R96.2
SDA11: J45.3, J46.3, J48.2, R104.1, R105.2
SDA_LV: R4.1, U1.9
SDA_LV1: R15.1, U2.9
SDA_LV2: R24.1, U3.9
SDA_LV3: R33.1, U4.9
SDA_LV4: R42.1, U5.9
SDA_LV5: R51.1, U6.9
SDA_LV6: R60.1, U7.9
SDA_LV7: R69.1, U8.9
SDA_LV8: R78.1, U9.9
SDA_LV9: R87.1, U10.9
SDA_LV10: R96.1, U11.9
SDA_LV11: R105.1, U12.9
TXLV: R6.1, U1.13
TXLV1: R11.1, U2.13
TXLV2: R20.1, U3.13
TXLV3: R29.1, U4.13
TXLV4: R38.1, U5.13
TXLV5: R47.1, U6.13
TXLV6: R56.1, U7.13
TXLV7: R65.1, U8.13
TXLV8: R74.1, U9.13
TXLV9: R83.1, U10.13
TXLV10: R92.1, U11.13
TXLV11: R101.1, U12.13
TXO: J4.5, R6.2
TXO1: J7.5, R11.2
TXO2: J11.5, R20.2
TXO3: J15.5, R29.2
TXO4: J19.5, R38.2
TXO5: J23.5, R47.2
TXO6: J27.5, R56.2
TXO7: J31.5, R65.2
TXO8: J35.5, R74.2
TXO9: J39.5, R83.2
TXO10: J43.5, R92.2
TXO11: J47.5, R101.2

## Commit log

2023-02-13 Add schematic, board, module lib.
    v01 of board complete.
    [SparkFun_u-blox_SAM-M10Q.brd, SparkFun_u-blox_SAM-M10Q.sch]
2023-02-13 Update for v10, Panelize. Add measures.
    [SparkFun_u-blox_SAM-M10Q-Panel.GBL, SparkFun_u-blox_SAM-M10Q-Panel.GBO, SparkFun_u-blox_SAM-M10Q-Panel.GBP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]
2023-02-14 Update post design review.
    Swap for updated reflowable battery.
    Adjust note for battery accordingly.
    Add qwiic symbol in schematic, replacing silk only on board.
    Expand t/b keepout under M10Q.
    Swap SCL/SDA silk so they are on the correct pins.
    [SparkFun_u-blox_SAM-M10Q-Panel.brd, SparkFun_u-blox_SAM-M10Q.brd, SparkFun_u-blox_SAM-M10Q.sch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]
2023-02-14 Rework paste for DFM experiment.
    Move original panel into 100_paste folder.
    Repanelize with quad box paste and put into quad_paste folder.
    Update library to have new variant.
    Update sch and brd with new part.
    [SparkFun_u-blox_SAM-M10Q-Panel.GBL, SparkFun_u-blox_SAM-M10Q-Panel.GBO, SparkFun_u-blox_SAM-M10Q-Panel.GBP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]
2023-04-05 Update for release
    Remove quad paste part from lib.
    Remove quad paste production folder.
    Move 100 paste up one folder.
    Update schematic/board for new part.
    [SparkFun_u-blox_SAM-M10Q-Panel.GBL, SparkFun_u-blox_SAM-M10Q-Panel.GBO, SparkFun_u-blox_SAM-M10Q-Panel.GBP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]
2023-07-26 Update introduction.md
    Updating Qwiic cable kit photo link

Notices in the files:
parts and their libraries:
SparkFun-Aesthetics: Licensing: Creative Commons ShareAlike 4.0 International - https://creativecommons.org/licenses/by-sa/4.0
